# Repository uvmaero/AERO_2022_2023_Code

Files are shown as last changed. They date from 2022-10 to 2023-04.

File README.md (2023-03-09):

# AERO_2022-2023
All of the code that drives each board and runs the car for the year 2022-2023!

## Overview
Each board is managed by an ESP32-WROOM, in the form of the official Dev-Kit-C V4 from Espressif. Its operations are managed by FreeRTOS and is clocked at 240Mhz.

## Boards
### Front Board
#### Description
Located in the front of the car, this board manages all driver input, the remote data aquisition system, and wireless communications with the steering wheel.
#### I/O
##### Inputs
- Accelorator pedal
- Brake pedal 
- Ready to drive button
- front wheel hall effect sensors
- front wheel ride height potentiometers
- CAN bus
##### Outputs
- CAN bus
- LoRa Radio
- ESP NOW data to wheel board
- Ready to drive LED
- Ready to drive buzzer 
#### Libraries
- LoRa

### Rear Board
#### Description
#### I/O
#### Libraries

### Wheel Board
#### Description
#### I/O
#### Libraries

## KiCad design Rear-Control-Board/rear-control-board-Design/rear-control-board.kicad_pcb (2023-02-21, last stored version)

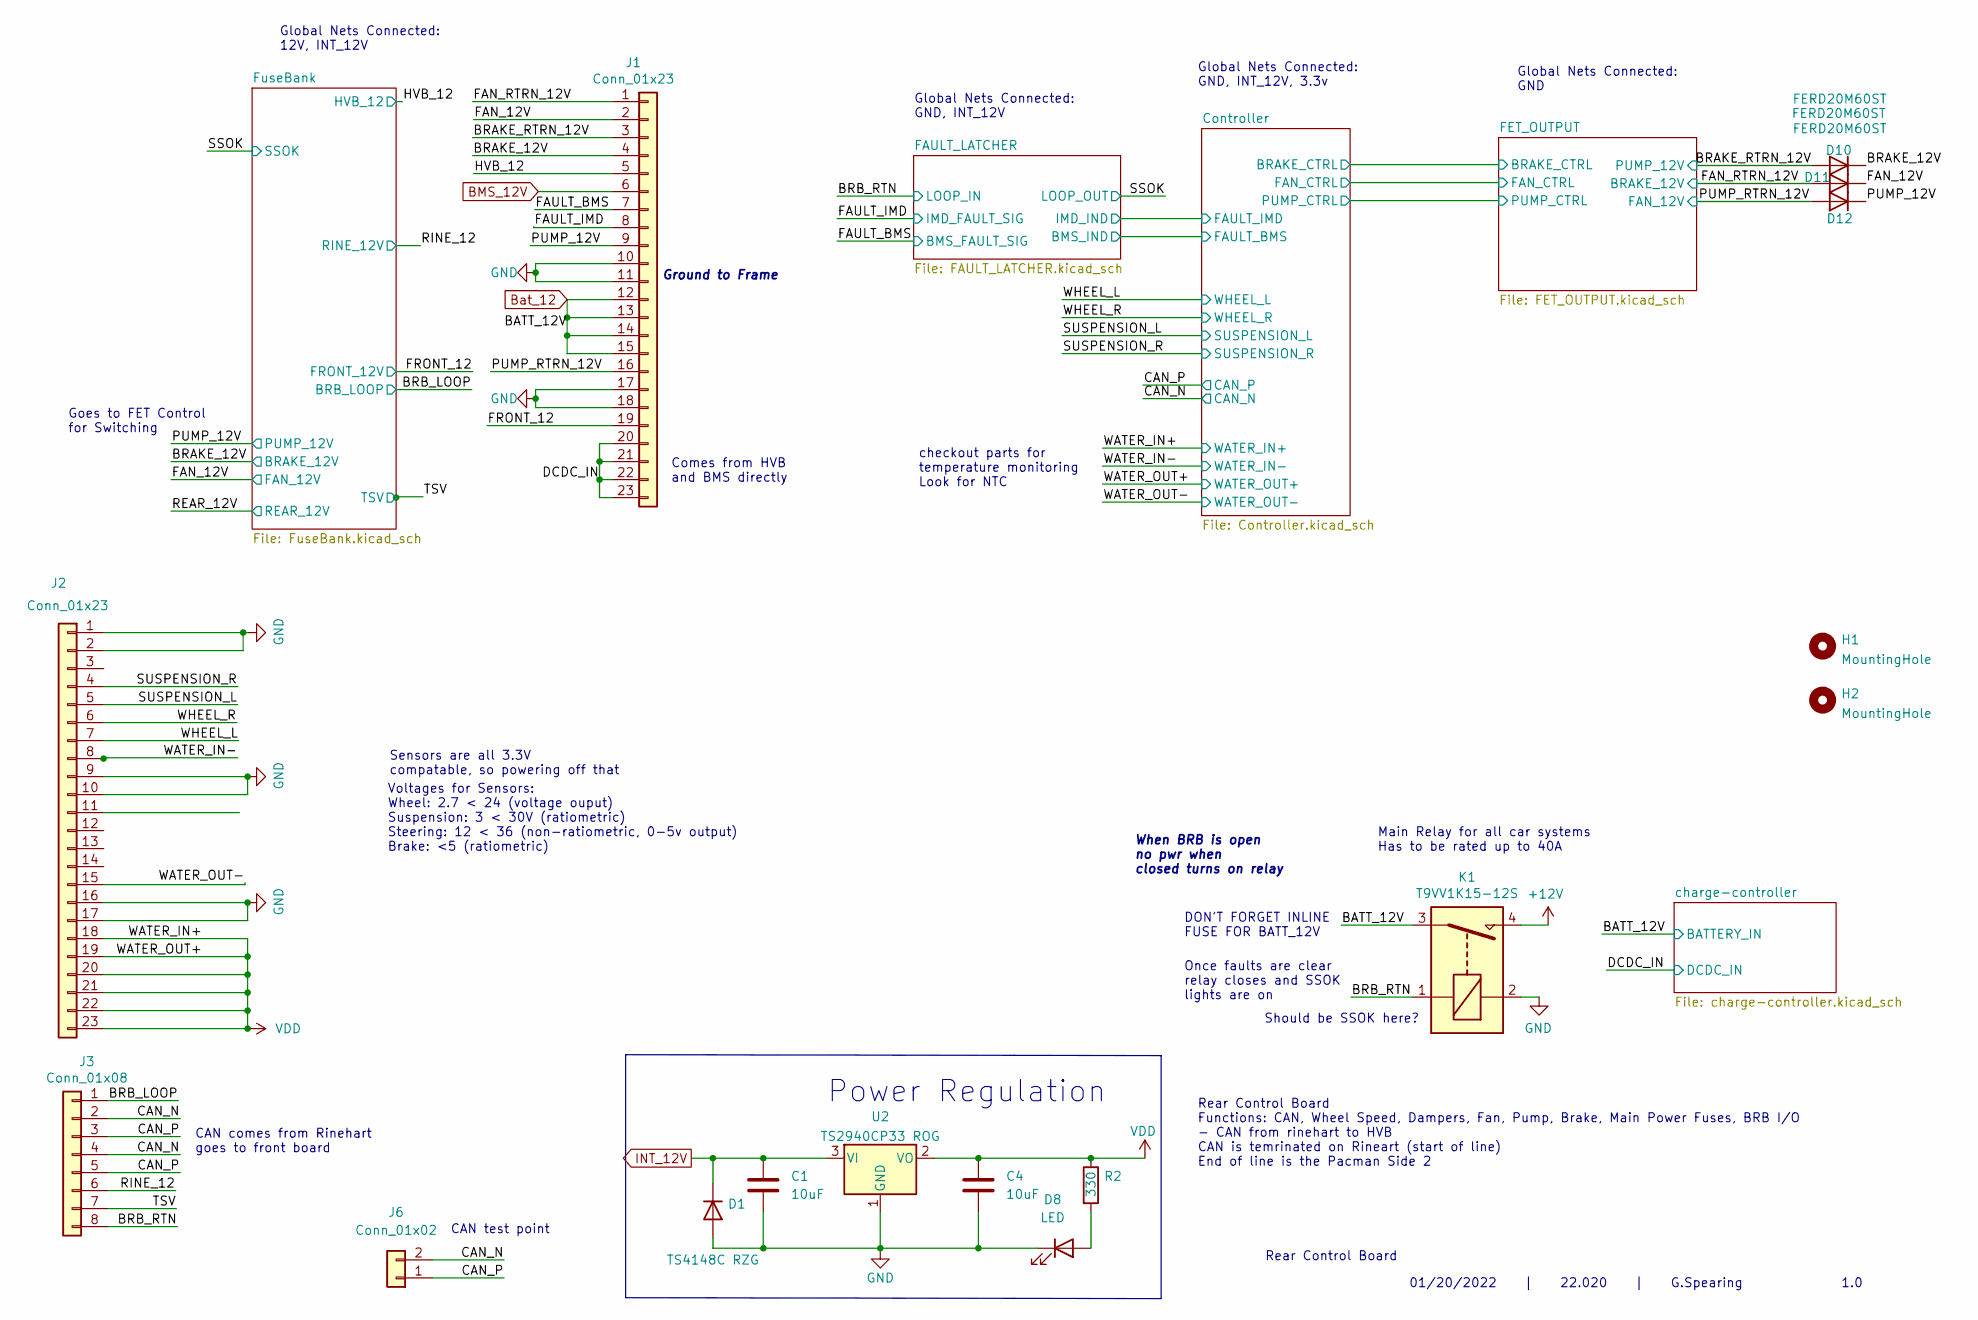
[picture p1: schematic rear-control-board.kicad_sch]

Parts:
C1, C4: 10uF; C_0603_1608Metric_Pad1.08x0.95mm_HandSolder
D1: TS4148C RZG; D_0603_1608Metric_Pad1.05x0.95mm_HandSolder
D8: LED; LED_0603_1608Metric_Pad1.05x0.95mm_HandSolder
D10, D11, D12: FERD20M60ST; TO-220-3_Vertical
H1, H2: MountingHole; MountingHole_3.2mm_M3
J1, J2: Conn_01x23; TE_1-770669-1_23pin_Horizontal
J3: Conn_01x08; TE_1-776280-1_8pin_Horizontal
J6: Conn_01x02; JST_NV_B02P-NV_1x02_P5.00mm_Vertical
K1: T9VV1K15-12S; RELAY_T9VV1K15-12S
R2: 330; R_0603_1608Metric_Pad0.98x0.95mm_HandSolder
U2: TS2940CP33 ROG; TO-252-2

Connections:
/BATT_12V: J1.12, J1.13, J1.14, J1.15, K1.3; also elsewhere on the board
/BRAKE_12V: D10.2 (K), J1.4; also elsewhere on the board
/BRAKE_RTRN_12V: D10.1 (A), J1.3; also elsewhere on the board
/BRB_LOOP: J3.1; also elsewhere on the board
/BRB_RTN: J3.8, K1.1; also elsewhere on the board
/CAN_N: J3.2, J3.4, J6.2; also elsewhere on the board
/CAN_P: J3.3, J3.5, J6.1; also elsewhere on the board
/DCDC_IN: J1.20, J1.21, J1.22, J1.23; also elsewhere on the board
/FAN_12V: D11.2 (K), J1.2; also elsewhere on the board
/FAN_RTRN_12V: D11.1 (A), J1.1; also elsewhere on the board
/FAULT_BMS: J1.7; also elsewhere on the board
/FAULT_IMD: J1.8; also elsewhere on the board
/FRONT_12: J1.19; also elsewhere on the board
/HVB_12: J1.5; also elsewhere on the board
/PUMP_12V: D12.2 (K), J1.9; also elsewhere on the board
/PUMP_RTRN_12V: D12.1 (A), J1.16; also elsewhere on the board
/RINE_12: J3.6; also elsewhere on the board
/SUSPENSION_L: J2.5; also elsewhere on the board
/SUSPENSION_R: J2.4; also elsewhere on the board
/TSV: J3.7; also elsewhere on the board
/WATER_IN-: J2.8; also elsewhere on the board
/WATER_OUT-: J2.15; also elsewhere on the board
/WHEEL_L: J2.7; also elsewhere on the board
/WHEEL_R: J2.6; also elsewhere on the board
BMS_12V: J1.6; also elsewhere on the board
GND: C1.2, C4.2, D1.2 (A), D8.1 (K), J1.10, J1.11, J1.17, J1.18, J2.1, J2.2, J2.9, J2.10, J2.16, J2.17, K1.2, U2.1 (GND); also elsewhere on the board
INT_12V: C1.1, D1.1 (K), U2.3 (VI); also elsewhere on the board
unnamed: D8.2 (A), R2.2
VDD: C4.1, J2.18, J2.19, J2.20, J2.21, J2.22, J2.23, R2.1, U2.2 (VO); also elsewhere on the board

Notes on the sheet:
Once faults are clear relay closes and SSOK lights are on
1.0
Comes from HVB and BMS directly
Should be SSOK here?
Global Nets Connected: GND
Main Relay for all car systems Has to be rated up to 40A
checkout parts for temperature monitoring Look for NTC
When BRB is open no pwr when closed turns on relay
Global Nets Connected: GND, INT_12V
Voltages for Sensors: Wheel: 2.7 < 24 (voltage ouput) Suspension: 3 < 30V (ratiometric) Steering: 12 < 36 (non-ratiometric, 0-5v output) Brake: <5 (ratiometric)
DON'T FORGET INLINE FUSE FOR BATT_12V
CAN test point
01/20/2022 | 22.020 | G.Spearing
Rear Control Board Functions: CAN, Wheel Speed, Dampers, Fan, Pump, Brake, Main Power Fuses, BRB I/O - CAN from rinehart to HVB CAN is temrinated on Rineart (start of line) End of line is the Pacman Side 2
Goes to FET Control for Switching
Ground to Frame
CAN comes from Rinehart goes to front board
Power Regulation
Global Nets Connected: GND, INT_12V, 3.3v
Sensors are all 3.3V compatable, so powering off that
Global Nets Connected: 12V, INT_12V
Rear Control Board

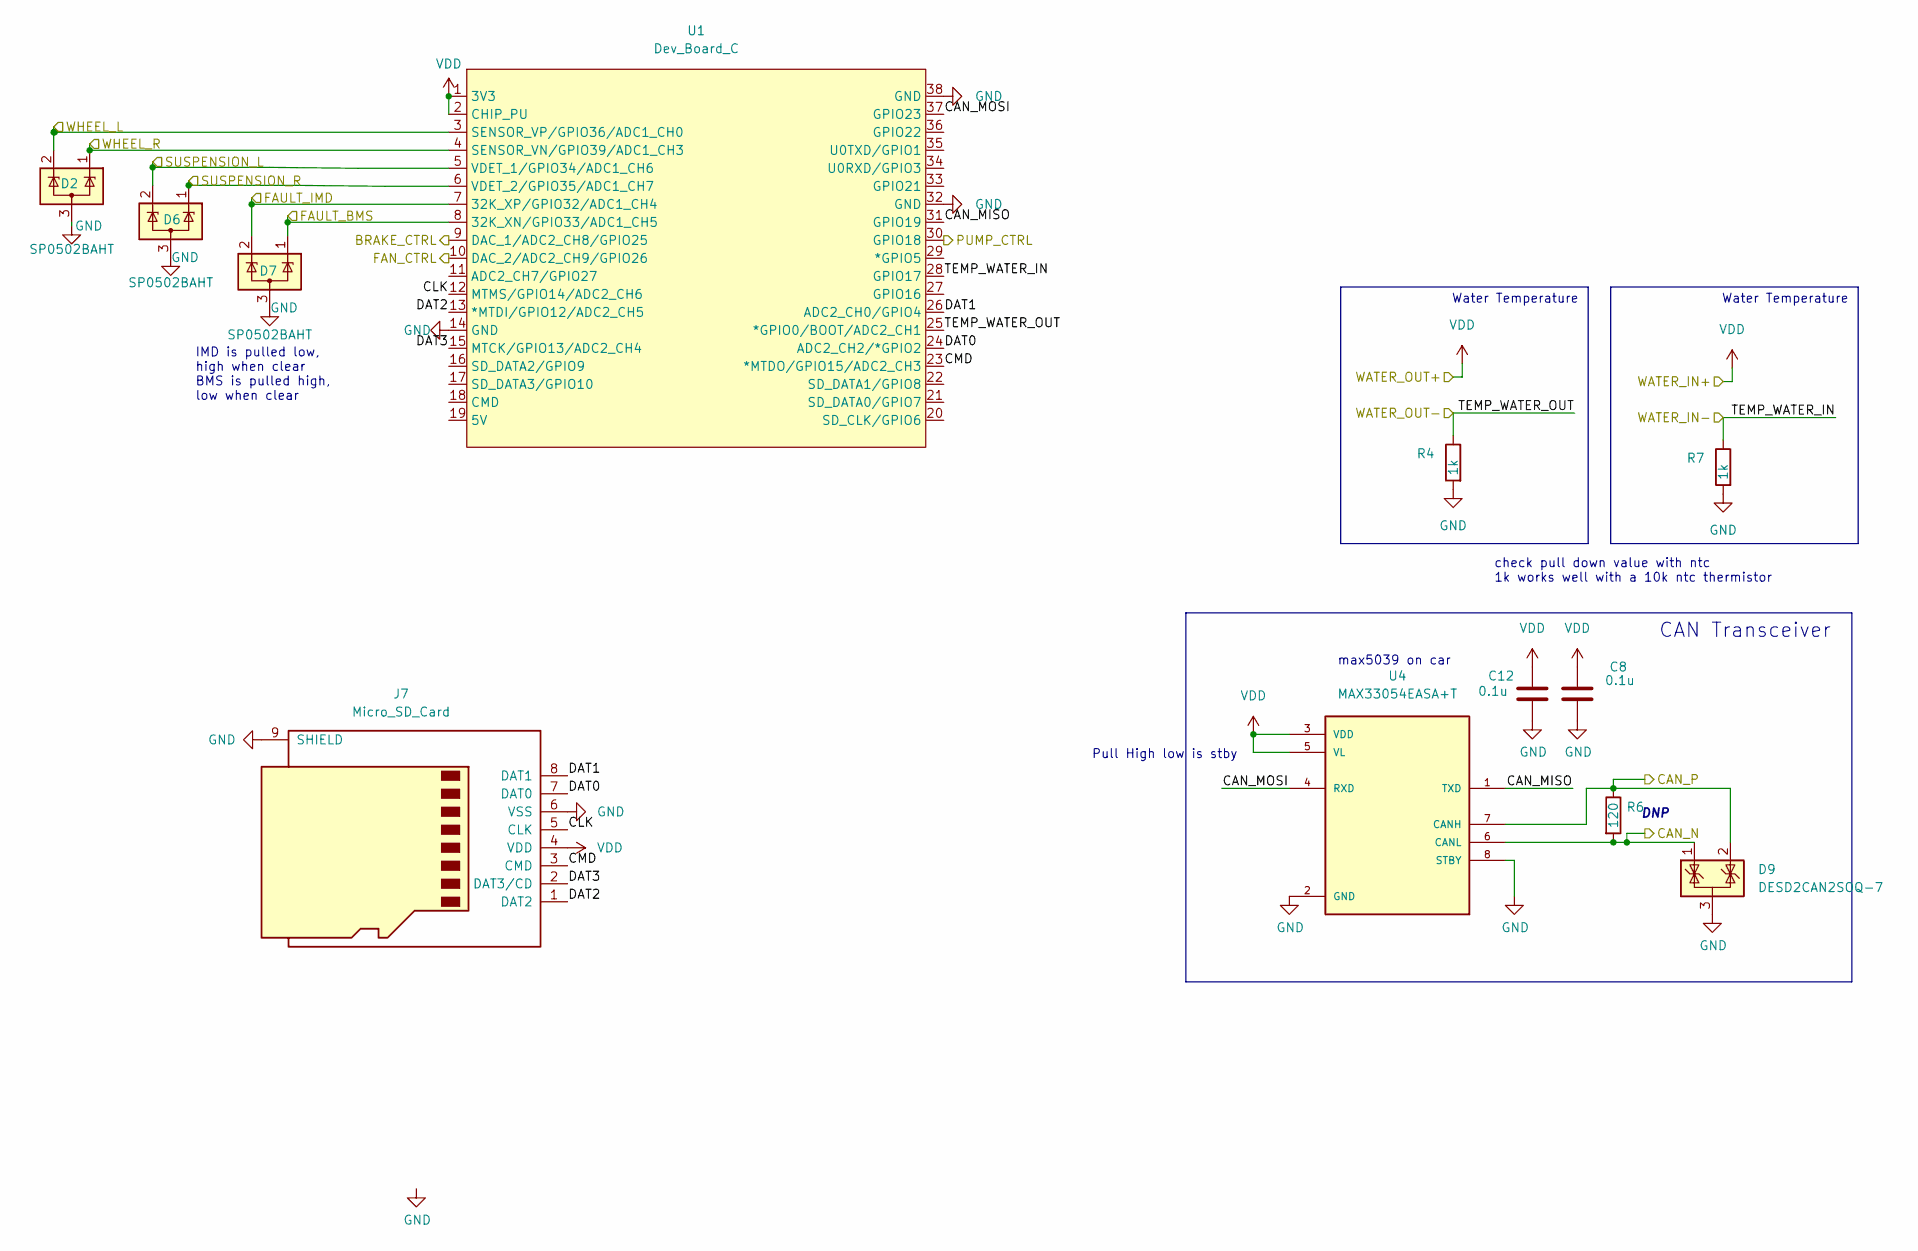
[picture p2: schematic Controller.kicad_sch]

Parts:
C8, C12: 0.1u; C_0603_1608Metric_Pad1.08x0.95mm_HandSolder
D2, D6, D7: SP0502BAHT; SOT-23
D9: DESD2CAN2SOQ-7; SOT-23
J7: Micro_SD_Card; microSD_HC_Wuerth_693072010801
R4, R7: 1k; R_0603_1608Metric_Pad0.98x0.95mm_HandSolder
R6: 120; R_0603_1608Metric_Pad0.98x0.95mm_HandSolder
U1: Dev_Board_C; ESP32-DevKitC
U4: MAX33054EASA+T; SOIC127P600X175-8N

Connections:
/CAN_N: D9.1 (K), R6.2, U4.6 (CANL); also elsewhere on the board
/CAN_P: D9.2 (K), R6.1, U4.7 (CANH); also elsewhere on the board
/Controller/BRAKE_CTRL: U1.9 (DAC_1/ADC2_CH8/GPIO25); also elsewhere on the board
/Controller/CAN_MISO: U1.31 (GPIO19), U4.1 (TXD)
/Controller/CAN_MOSI: U1.37 (GPIO23), U4.4 (RXD)
/Controller/CLK: J7.5 (CLK), U1.12 (MTMS/GPIO14/ADC2_CH6)
/Controller/CMD: J7.3 (CMD), U1.23 (*MTDO/GPIO15/ADC2_CH3)
/Controller/DAT0: J7.7 (DAT0), U1.24 (ADC2_CH2/*GPIO2)
/Controller/DAT1: J7.8 (DAT1), U1.26 (ADC2_CH0/GPIO4)
/Controller/DAT2: J7.1 (DAT2), U1.13 (*MTDI/GPIO12/ADC2_CH5)
/Controller/DAT3: J7.2 (DAT3/CD), U1.15 (MTCK/GPIO13/ADC2_CH4)
/Controller/FAN_CTRL: U1.10 (DAC_2/ADC2_CH9/GPIO26); also elsewhere on the board
/Controller/FAULT_IMD: D7.2 (K), U1.7 (32K_XP/GPIO32/ADC1_CH4); also elsewhere on the board
/Controller/PUMP_CTRL: U1.30 (GPIO18); also elsewhere on the board
/FAULT_LATCHER/BMS_SWITCH: D7.1 (K), U1.8 (32K_XN/GPIO33/ADC1_CH5); also elsewhere on the board
/SUSPENSION_L: D6.2 (K), U1.5 (VDET_1/GPIO34/ADC1_CH6); also elsewhere on the board
/SUSPENSION_R: D6.1 (K), U1.6 (VDET_2/GPIO35/ADC1_CH7); also elsewhere on the board
/WATER_IN-: R7.1, U1.28 (GPIO17); also elsewhere on the board
/WATER_OUT-: R4.1, U1.25 (*GPIO0/BOOT/ADC2_CH1); also elsewhere on the board
/WHEEL_L: D2.2 (K), U1.3 (SENSOR_VP/GPIO36/ADC1_CH0); also elsewhere on the board
/WHEEL_R: D2.1 (K), U1.4 (SENSOR_VN/GPIO39/ADC1_CH3); also elsewhere on the board
GND: C8.2, C12.2, D2.3 (A), D6.3 (A), D7.3 (A), D9.3 (A), J7.6 (VSS), J7.9 (SHIELD), R4.2, R7.2, U1.14 (GND), U1.32 (GND), U1.38 (GND), U4.2 (GND), U4.8 (STBY); also elsewhere on the board
VDD: C8.1, C12.1, J7.4 (VDD), U1.1 (3V3), U1.2 (CHIP_PU), U4.3 (VDD), U4.5 (VL); also elsewhere on the board

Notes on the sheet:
Water Temperature
check pull down value with ntc 1k works well with a 10k ntc thermistor
CAN Transceiver
IMD is pulled low, high when clear BMS is pulled high, low when clear
max5039 on car
Pull High low is stby
DNP

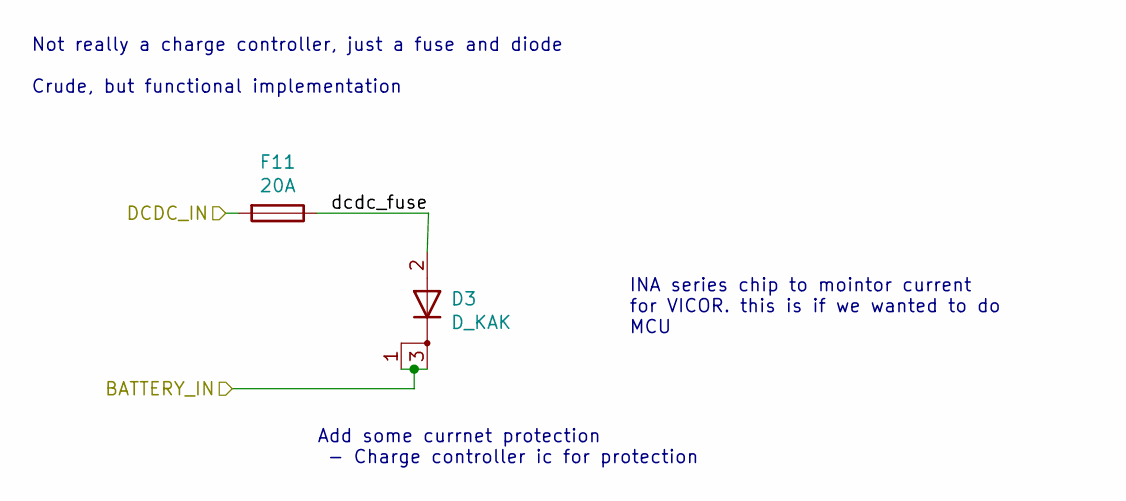
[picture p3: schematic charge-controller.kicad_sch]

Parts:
D3: D_KAK; TO-252-2
F11: 20A; Fuseholder_Blade_Mini_Keystone_3568

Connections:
/BATT_12V: D3.1 (K), D3.3 (K); also elsewhere on the board
/DCDC_IN: F11.2; also elsewhere on the board
/charge-controller/dcdc_fuse: D3.2 (A), F11.1

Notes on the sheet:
Add some currnet protection - Charge controller ic for protection
Not really a charge controller, just a fuse and diode Crude, but functional implementation
INA series chip to mointor current for VICOR. this is if we wanted to do MCU

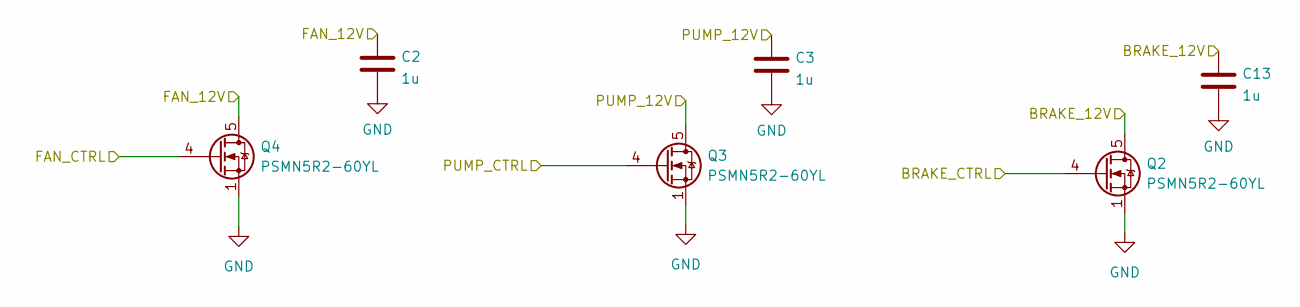
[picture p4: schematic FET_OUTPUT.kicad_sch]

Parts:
C2, C3, C13: 1u; C_0603_1608Metric_Pad1.08x0.95mm_HandSolder
Q2, Q3, Q4: PSMN5R2-60YL; LFPAK56

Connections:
/BRAKE_RTRN_12V: C3.1, Q3.5 (D); also elsewhere on the board
/Controller/BRAKE_CTRL: Q2.4 (G); also elsewhere on the board
/Controller/FAN_CTRL: Q4.4 (G); also elsewhere on the board
/Controller/PUMP_CTRL: Q3.4 (G); also elsewhere on the board
/FAN_RTRN_12V: C13.1, Q2.5 (D); also elsewhere on the board
/PUMP_RTRN_12V: C2.1, Q4.5 (D); also elsewhere on the board
GND: C2.2, C3.2, C13.2, Q2.1 (S), Q2.2 (S), Q2.3 (S), Q3.1 (S), Q3.2 (S), Q3.3 (S), Q4.1 (S), Q4.2 (S), Q4.3 (S); also elsewhere on the board

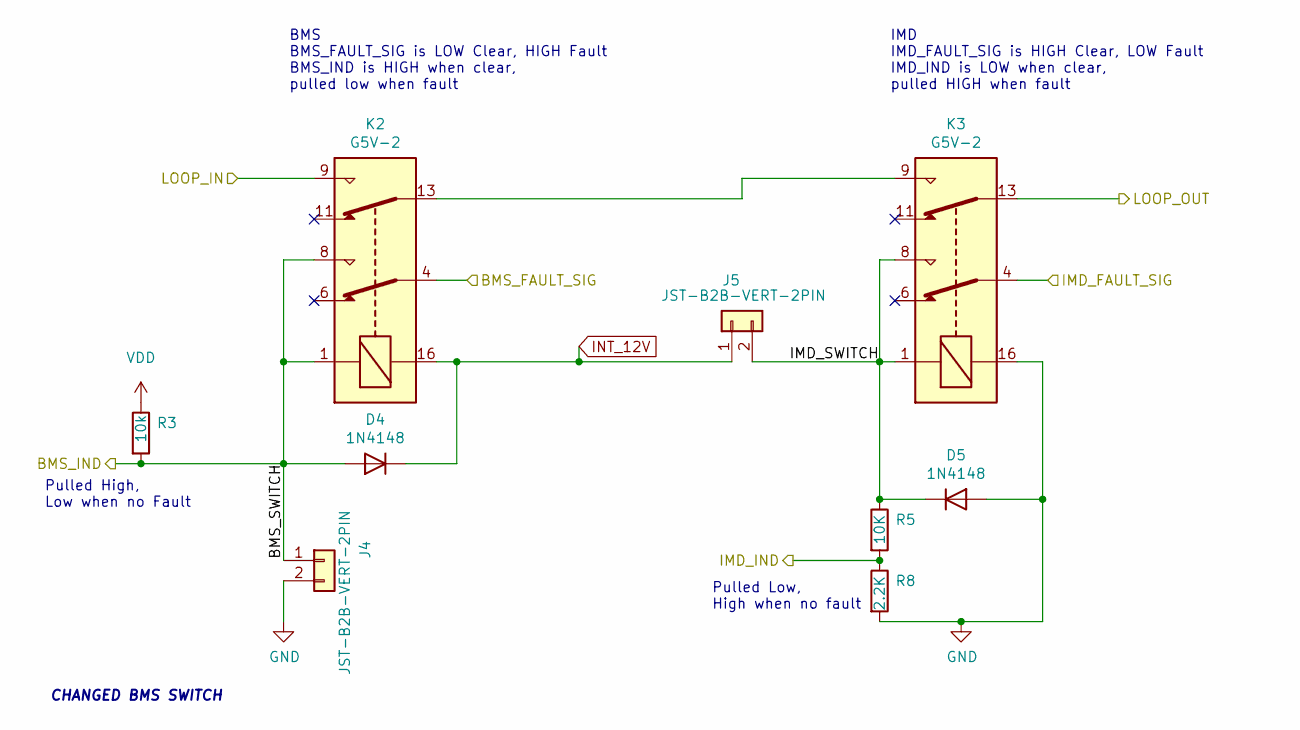
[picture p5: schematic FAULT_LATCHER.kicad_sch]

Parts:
D4, D5: 1N4148; D_SOD-123
J4, J5: JST-B2B-VERT-2PIN; JST_XH_B2B-XH-AM_1x02_P2.50mm_Vertical
K2, K3: G5V-2; Relay_DPDT_Omron_G5V-2
R3: 10k; R_0603_1608Metric_Pad0.98x0.95mm_HandSolder
R5: 10K; R_0603_1608Metric_Pad0.98x0.95mm_HandSolder
R8: 2.2K; R_0603_1608Metric_Pad0.98x0.95mm_HandSolder

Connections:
/BRB_RTN: K2.9; also elsewhere on the board
/Controller/FAULT_IMD: R5.2, R8.1; also elsewhere on the board
/FAULT_BMS: K2.4; also elsewhere on the board
/FAULT_IMD: K3.4; also elsewhere on the board
/FAULT_LATCHER/BMS_SWITCH: D4.2 (A), J4.1, K2.1, K2.8, R3.2; also elsewhere on the board
/FAULT_LATCHER/IMD_SWITCH: D5.1 (K), J5.2, K3.1, K3.8, R5.1
/SSOK: K3.13; also elsewhere on the board
GND: D5.2 (A), J4.2, K3.16, R8.2; also elsewhere on the board
INT_12V: D4.1 (K), J5.1, K2.16; also elsewhere on the board
unnamed: K2.13, K3.9
VDD: R3.1; also elsewhere on the board

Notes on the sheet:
Pulled High, Low when no Fault
IMD IMD_FAULT_SIG is HIGH Clear, LOW Fault IMD_IND is LOW when clear, pulled HIGH when fault
Pulled Low, High when no fault
BMS BMS_FAULT_SIG is LOW Clear, HIGH Fault BMS_IND is HIGH when clear, pulled low when fault
CHANGED BMS SWITCH

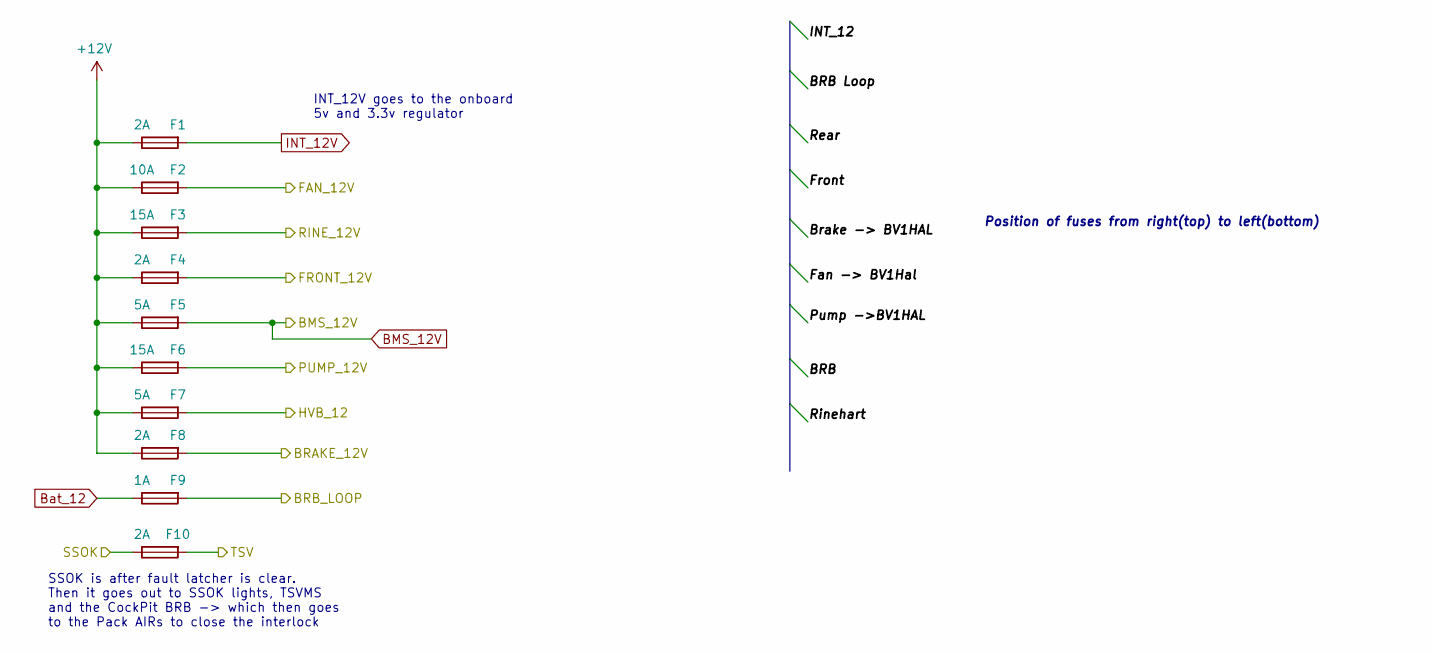
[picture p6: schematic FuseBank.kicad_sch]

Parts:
F1, F4, F8, F10: 2A; Fuseholder_Blade_Mini_Keystone_3568
F2: 10A; Fuseholder_Blade_Mini_Keystone_3568
F3, F6: 15A; Fuseholder_Blade_Mini_Keystone_3568
F5, F7: 5A; Fuseholder_Blade_Mini_Keystone_3568
F9: 1A; Fuseholder_Blade_Mini_Keystone_3568

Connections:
/BRAKE_12V: F8.2; also elsewhere on the board
/BRB_LOOP: F9.2; also elsewhere on the board
/FAN_12V: F2.2; also elsewhere on the board
/FRONT_12: F4.2; also elsewhere on the board
/HVB_12: F7.2; also elsewhere on the board
/PUMP_12V: F6.2; also elsewhere on the board
/RINE_12: F3.2; also elsewhere on the board
/SSOK: F10.1; also elsewhere on the board
/TSV: F10.2; also elsewhere on the board
BMS_12V: F5.2; also elsewhere on the board
INT_12V: F1.2; also elsewhere on the board

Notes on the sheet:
SSOK is after fault latcher is clear. Then it goes out to SSOK lights, TSVMS and the CockPit BRB -> which then goes to the Pack AIRs to close the interlock
Position of fuses from right(top) to left(bottom)
INT_12V goes to the onboard 5v and 3.3v regulator

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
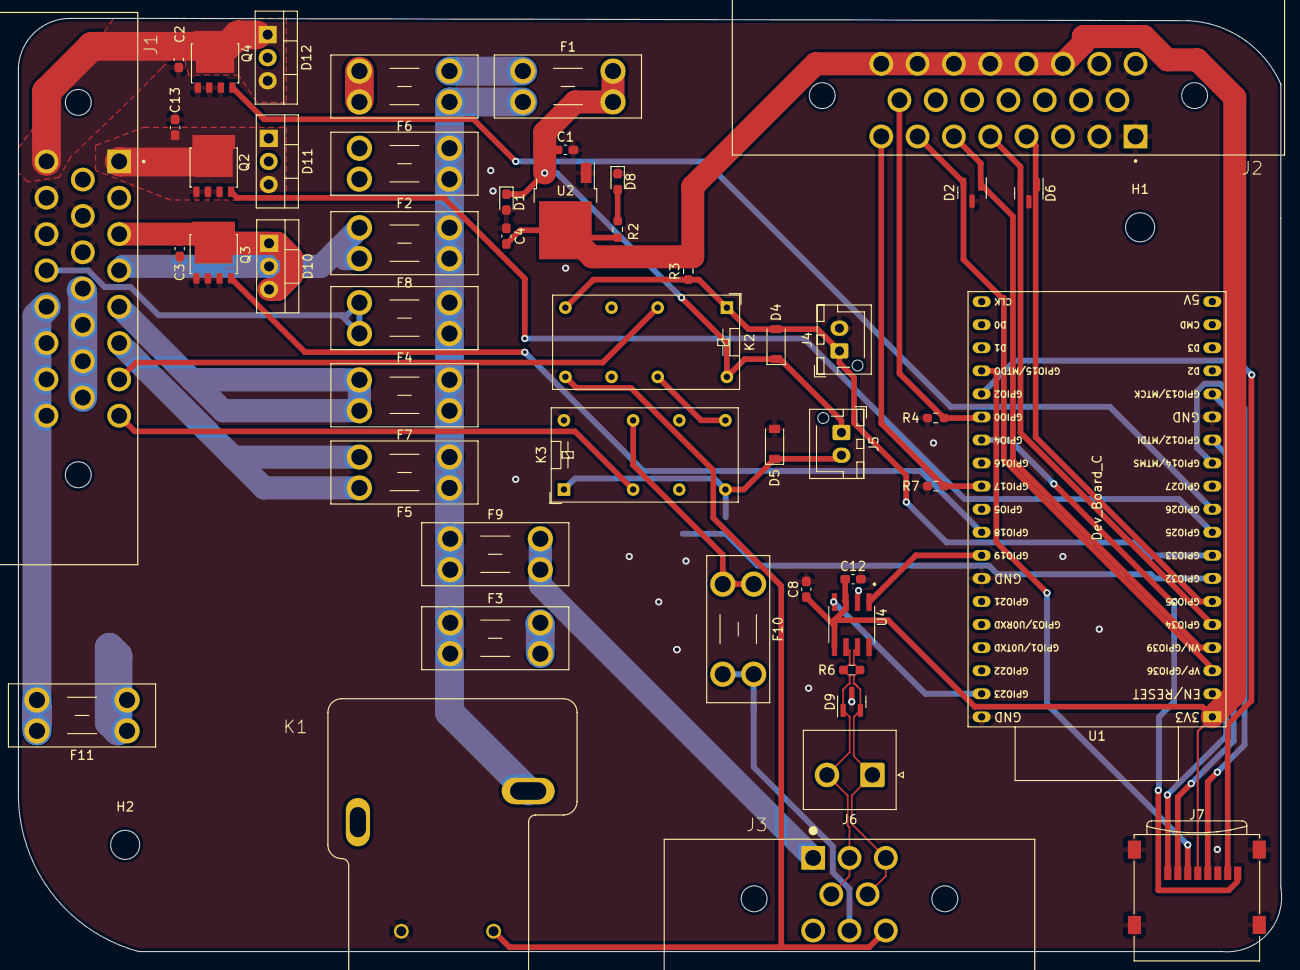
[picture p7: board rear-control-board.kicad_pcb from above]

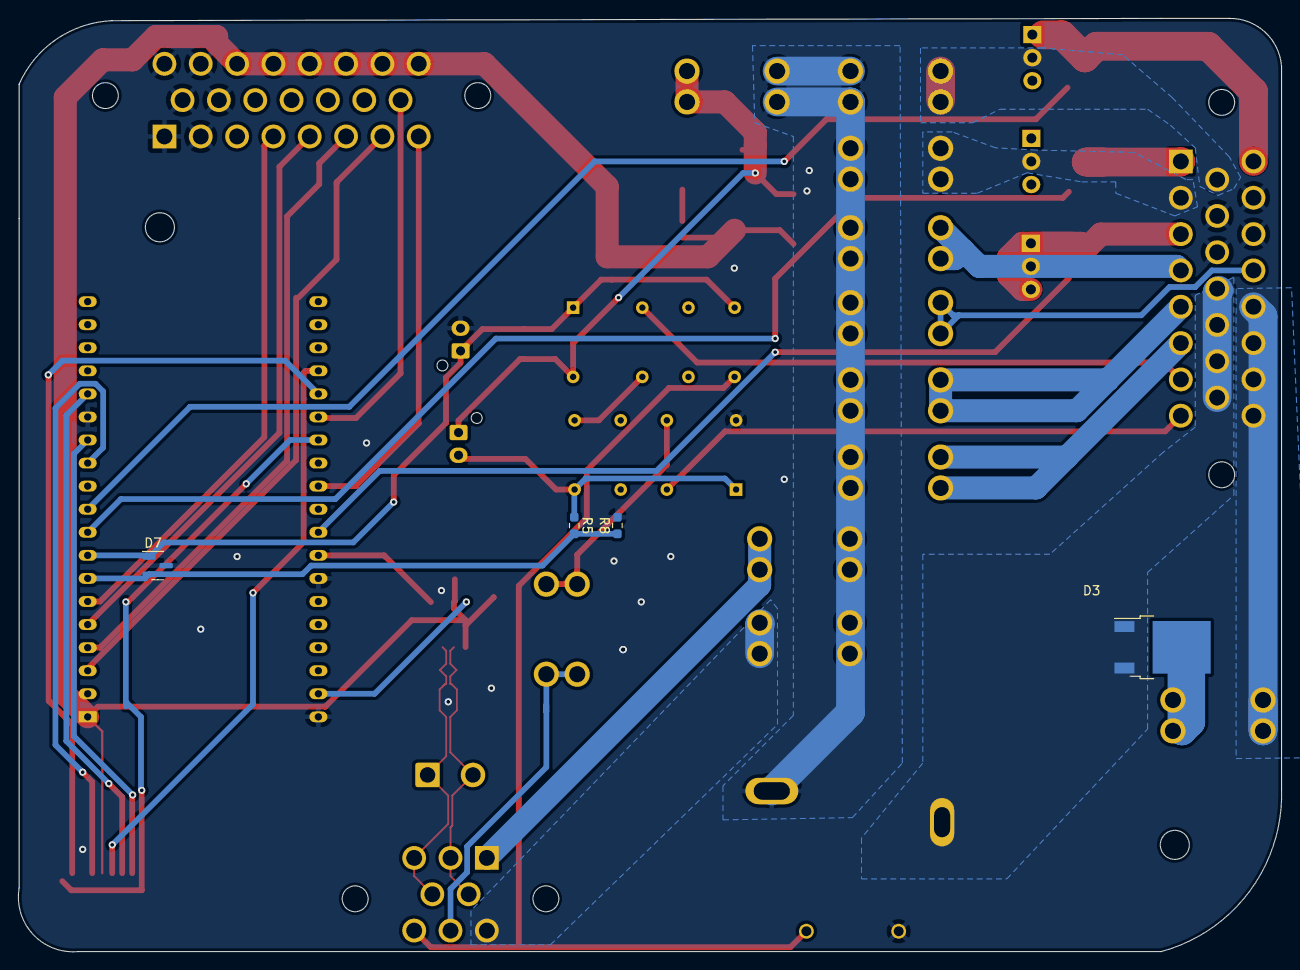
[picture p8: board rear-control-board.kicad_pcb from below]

Board: 2 copper layers, 139.1 x 102.8 mm, 55 parts (4 on the bottom side), 47 nets.

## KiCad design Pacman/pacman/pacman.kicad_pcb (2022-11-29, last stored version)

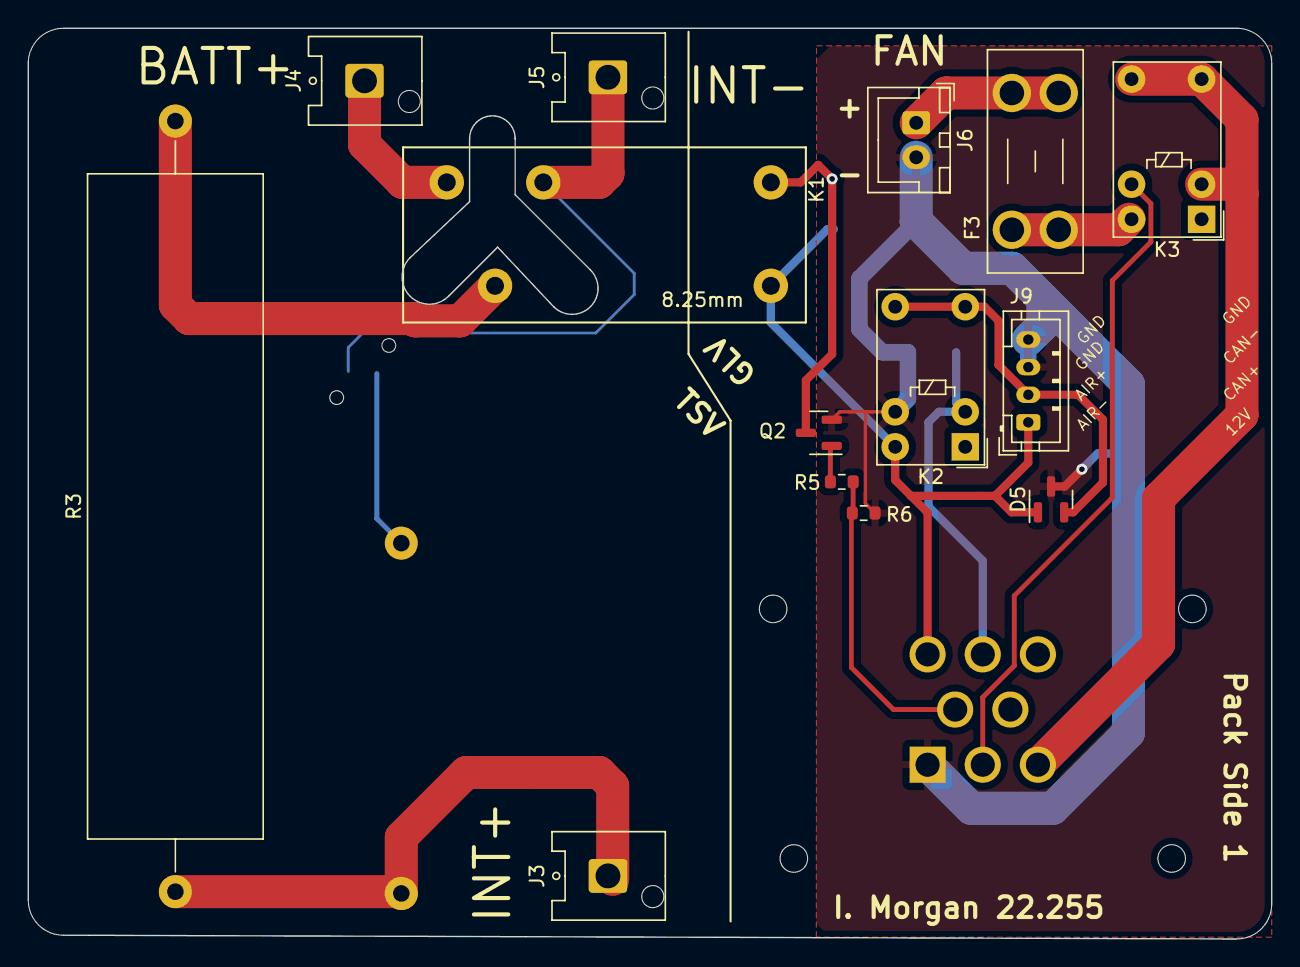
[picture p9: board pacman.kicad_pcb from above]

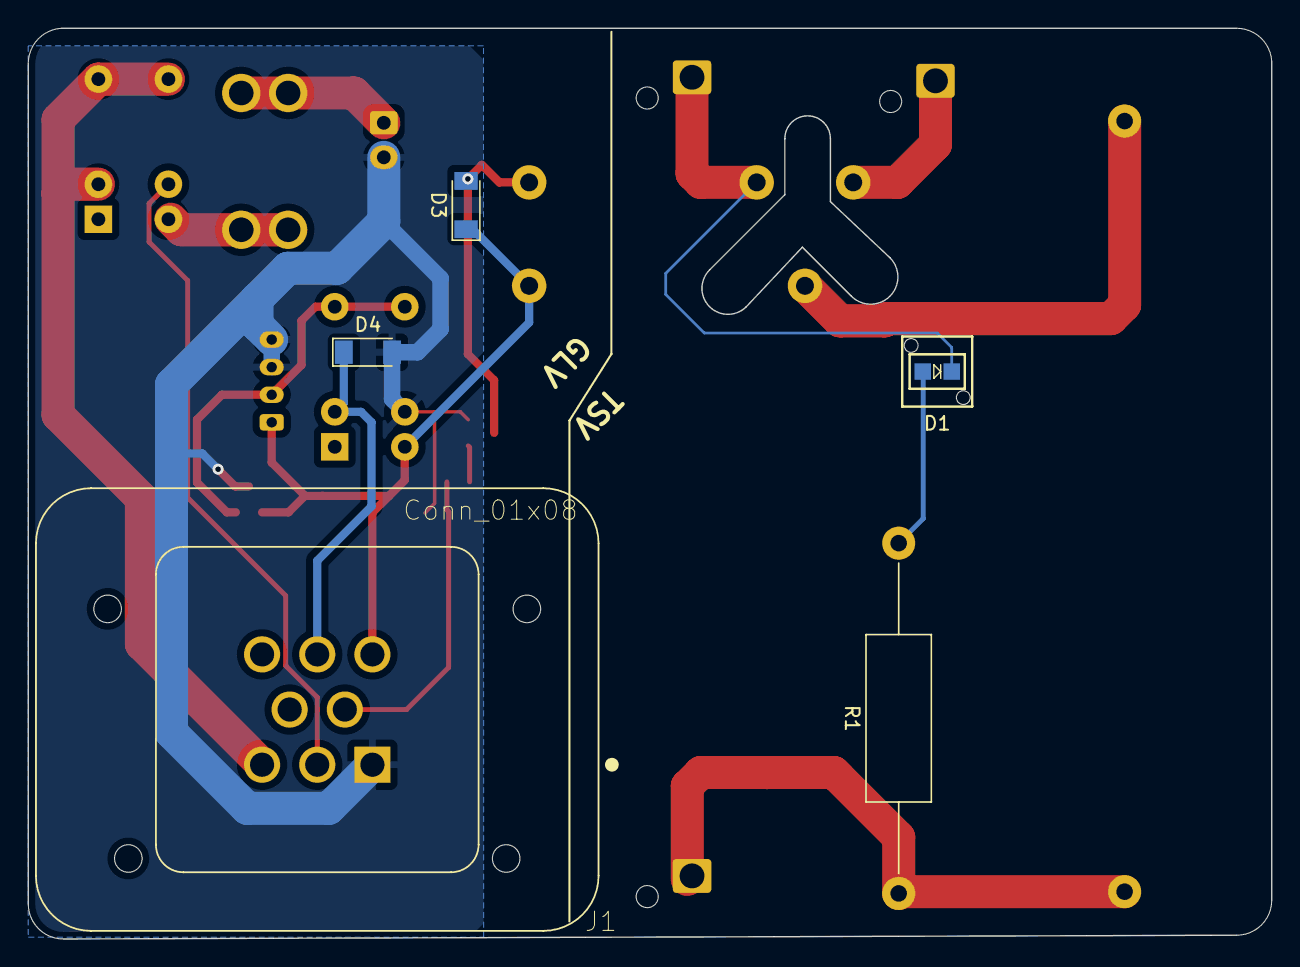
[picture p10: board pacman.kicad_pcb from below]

Board: 2 copper layers, 90.2 x 66.0 mm, 19 parts (5 on the bottom side), 16 nets.

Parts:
D1: LED; LPA-C011301S-x LED 0805 LIGHT PIPE SINGLE VERT SMD
D3, D4: 1N4148; D_MiniMELF
D5: MMBZxx; SOT-23
F3: Fuse; Fuseholder_Blade_Mini_Keystone_3568
J1: Conn_01x08; TE_1-776276-1_8pin_Vertical
J3, J4, J5: Conn_01x01; Hirose_DF63M-1P-3.96DSA_1x01_P3.96mm_Vertical
J6: Conn_01x02; JST_XH_B2B-XH-A_1x02_P2.50mm_Vertical
J9: JST PH; JST_PH_B4B-PH-K_1x04_P2.00mm_Vertical
K1: G2RL
K2, K3: G5V-1; Relay_SPDT_Omron_G5V-1
Q2: MMBT2222A; SOT-23
R1: 1.5k; R_Axial_DIN0414_L11.9mm_D4.5mm_P25.40mm_Horizontal
R3: 500; R_Axial_Power_L48.0mm_W12.5mm_P55.88mm
R5: 10k; R_0603_1608Metric
R6: 2k; R_0603_1608Metric

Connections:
+12V: J1.3, K3.2, K3.5, K3.6
/AIR_B+: D5.2 (K), J9.2, K2.5, K2.6
/AIR_B-: D3.1 (K), D5.1 (K), J1.6, J9.1, K1.2, K2.10
/B+: J4.1, K1.10
/BMS_FAN: J1.2, K3.9
/FAN_OUT: F3.1, K3.10
/INT+: J3.1, R1.1, R3.1
/INT-: D1.1 (K), J5.1, K1.1
/MAIN_CONT: D4.1 (K), J1.7, K2.2
/PRECHARGE: J1.4, R5.2, R6.2
GND: D4.2 (A), D5.3 (A), J1.1, J6.2, J9.3, J9.4, K2.9, Q2.2 (E), R6.1
unnamed: D1.2 (A), R1.2
unnamed: D3.2 (A), K1.9, Q2.3 (C)
unnamed: F3.2, J6.1
unnamed: K1.5, R3.2
unnamed: Q2.1 (B), R5.1

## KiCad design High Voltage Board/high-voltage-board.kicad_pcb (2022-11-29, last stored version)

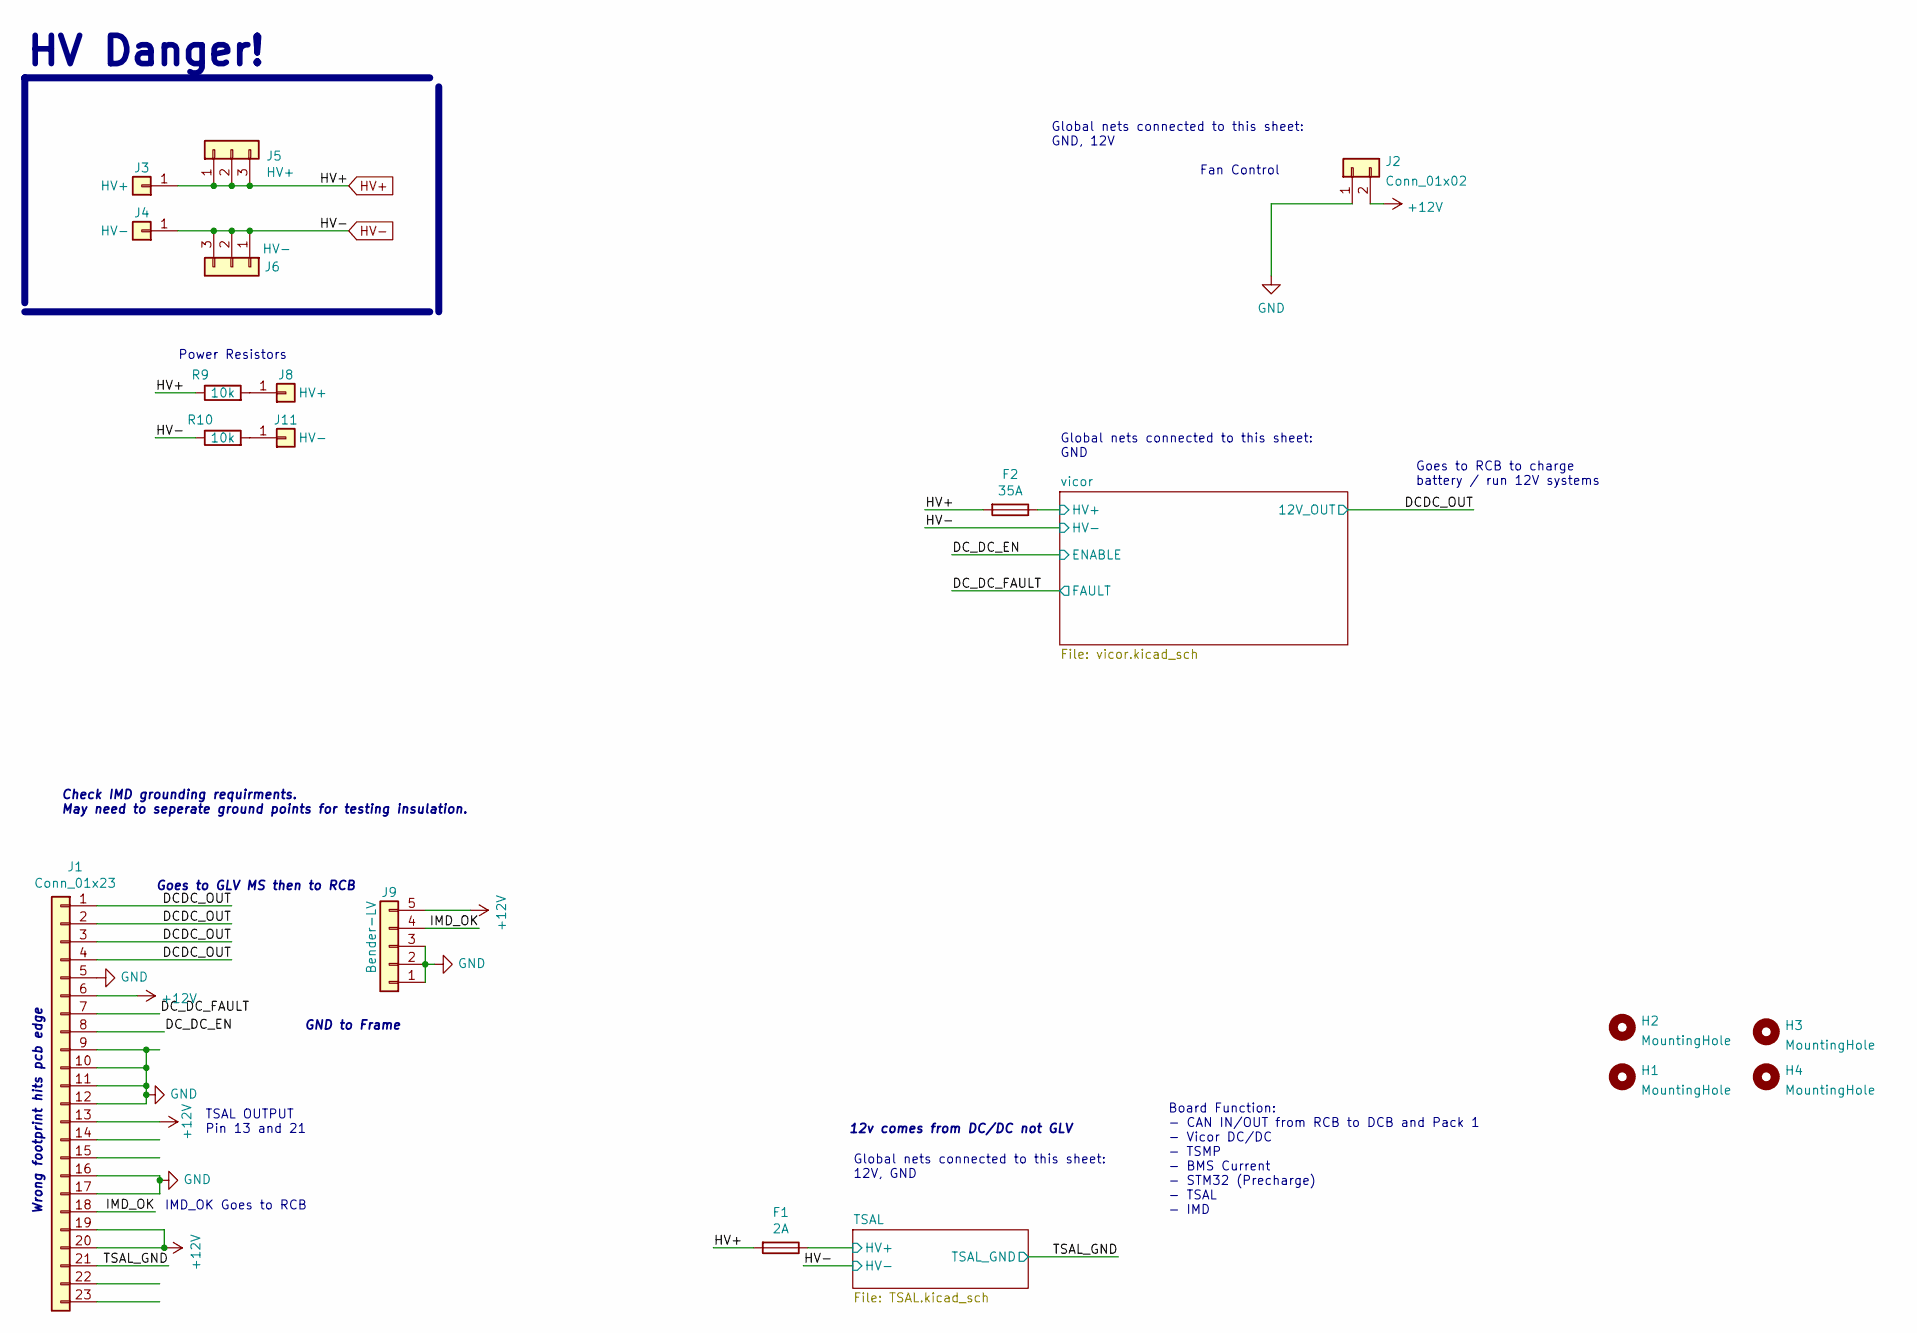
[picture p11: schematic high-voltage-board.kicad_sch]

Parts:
F1: 2A; Fuseholder_Cylinder-5x20mm_Schurter_0031_8201_Horizontal_Op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
F2: 35A; Fuseholder_Cylinder-5x20mm_Schurter_0031_8201_Horizontal_Op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
H1, H2, H3, H4: MountingHole; MountingHole_3.2mm_M3
J1: Conn_01x23; TE_1-770669-1_23pin_Horizontal
J2: Conn_01x02; JST_XH_B2B-XH-A_1x02_P2.50mm_Vertical
J3, J8: HV+; Hirose_DF63M-1P-3.96DSA_1x01_P3.96mm_Vertical
J4, J11: HV-; Hirose_DF63M-1P-3.96DSA_1x01_P3.96mm_Vertical
J5: HV+; TE_MATE-N-LOK_1-770870-x_1x03_P4.14mm_Vertical
J6: HV-; TE_MATE-N-LOK_1-770870-x_1x03_P4.14mm_Vertical
J9: Bender-LV; JST_XH_B5B-XH-A_1x05_P2.50mm_Vertical
R9, R10: 10k; R_Axial_Power_L50.0mm_W9.0mm_P60.96mm

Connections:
+12V: J1.6, J1.13, J1.19, J1.20, J2.2, J9.5; also elsewhere on the board
/DCDC_OUT: J1.1, J1.2, J1.3, J1.4; also elsewhere on the board
/DC_DC_EN: J1.8; also elsewhere on the board
/DC_DC_FAULT: J1.7; also elsewhere on the board
/IMD_OK: J1.18, J9.4
/TSAL/HV+: F1.1; also elsewhere on the board
/TSAL_GND: J1.21; also elsewhere on the board
/vicor/HV+: F2.1; also elsewhere on the board
GND: J1.5, J1.9, J1.10, J1.11, J1.12, J1.16, J1.17, J2.1, J9.1, J9.2, J9.3; also elsewhere on the board
HV+: F1.2, F2.2, J3.1, J5.1, J5.2, J5.3, R9.1
HV-: J4.1, J6.1, J6.2, J6.3, R10.1; also elsewhere on the board
unnamed: J8.1, R9.2
unnamed: J11.1, R10.2

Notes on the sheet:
Global nets connected to this sheet: GND, 12V
Global nets connected to this sheet: 12V, GND
IMD_OK Goes to RCB
Goes to RCB to charge battery / run 12V systems
TSAL OUTPUT Pin 13 and 21
Board Function: - CAN IN/OUT from RCB to DCB and Pack 1 - Vicor DC/DC - TSMP - BMS Current - STM32 (Precharge) - TSAL - IMD
Power Resistors
12v comes from DC/DC not GLV
Goes to GLV MS then to RCB
Fan Control
GND to Frame
Global nets connected to this sheet: GND
HV Danger!
Check IMD grounding requirments. May need to seperate ground points for testing insulation.
Wrong footprint hits pcb edge

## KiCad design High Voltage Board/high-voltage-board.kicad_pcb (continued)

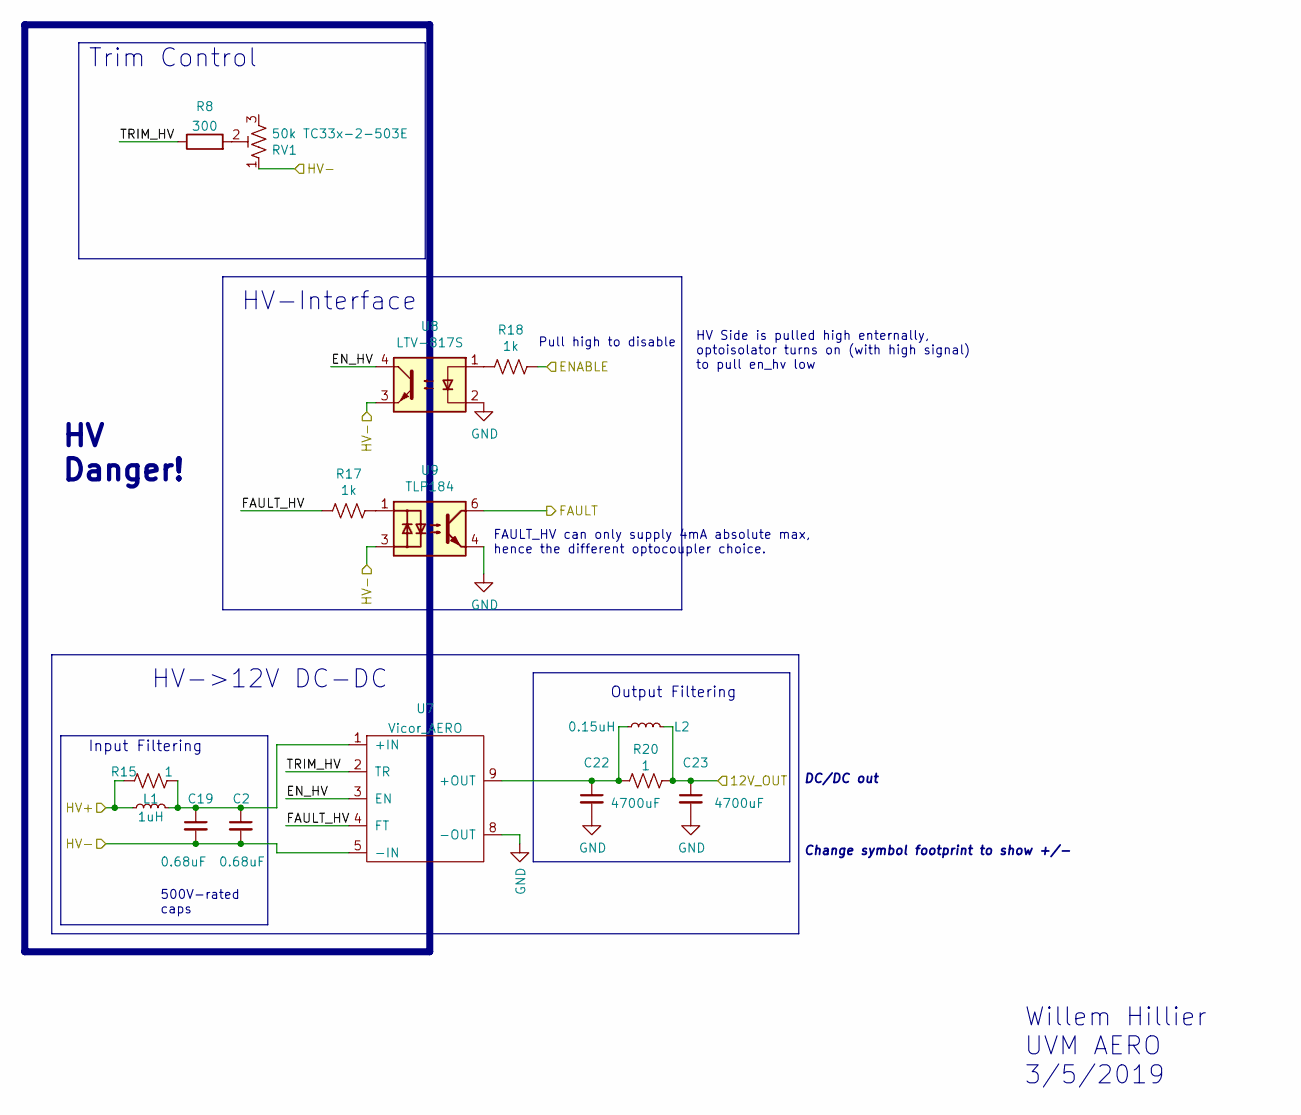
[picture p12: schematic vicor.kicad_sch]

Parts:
C2, C19: 0.68uF; C_Rect_L18.0mm_W8.0mm_P15.00mm_FKS3_FKP3
C22, C23: 4700uF; C_Radial_D18.0mm_H35.5mm_P7.50mm
L1: 1uH; L_1008_2520Metric_Pad1.43x2.20mm_HandSolder
L2: 0.15uH; L_0805_2012Metric_Pad1.15x1.40mm_HandSolder
R8: 300; R_0603_1608Metric_Pad0.98x0.95mm_HandSolder
R15, R20: 1; R_2512_6332Metric_Pad1.40x3.35mm_HandSolder
R17, R18: 1k; R_0603_1608Metric_Pad0.98x0.95mm_HandSolder
RV1: 50k TC33x-2-503E; Potentiometer_Bourns_TC33X_Vertical
U7: Vicor_AERO; vicor-socket-no-cutouts
U8: LTV-817S; SMDIP-4_W9.53mm_Clearance8mm
U9: TLP184; MFSOP6-4_4.4x3.6mm_P1.27mm

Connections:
/DCDC_OUT: C23.1, L2.2, R20.1; also elsewhere on the board
/DC_DC_EN: R18.1; also elsewhere on the board
/DC_DC_FAULT: U9.6; also elsewhere on the board
/vicor/EN_HV: U7.3 (EN), U8.4
/vicor/FAULT_HV: R17.2, U7.4 (FT)
/vicor/HV+: L1.1, R15.2; also elsewhere on the board
/vicor/TRIM_HV: R8.1, U7.2 (TR)
GND: C22.2, C23.2, U7.8 (-OUT), U8.2, U9.4; also elsewhere on the board
HV-: C2.2, C19.2, RV1.1, U7.5 (-IN), U8.3, U9.3; also elsewhere on the board
unnamed: C2.1, C19.1, L1.2, R15.1, U7.1 (+IN)
unnamed: C22.1, L2.1, R20.2, U7.9 (+OUT)
unnamed: R8.2, RV1.2
unnamed: R17.1, U9.1
unnamed: R18.2, U8.1

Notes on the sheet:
DC/DC out
Output Filtering
500V-rated caps
Willem Hillier UVM AERO 3/5/2019
Input Filtering
Trim Control
HV-Interface
Change symbol footprint to show +/-
Pull high to disable
HV->12V DC-DC
HV Side is pulled high enternally, optoisolator turns on (with high signal) to pull en_hv low
HV Danger!
FAULT_HV can only supply 4mA absolute max, hence the different optocoupler choice.


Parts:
C4, C5: 0.1u; C_0603_1608Metric_Pad1.08x0.95mm_HandSolder
C6: 1u; C_0603_1608Metric_Pad1.08x0.95mm_HandSolder
Q1, Q2: PSMN5R2-60YL; LFPAK56
R1: 39k; R_Axial_DIN0411_L9.9mm_D3.6mm_P25.40mm_Horizontal
R2, R5: 10k; R_0603_1608Metric_Pad0.98x0.95mm_HandSolder
R3: 100k; R_0603_1608Metric_Pad0.98x0.95mm_HandSolder
R4: 235k; R_0603_1608Metric_Pad0.98x0.95mm_HandSolder
R6: 0.75; R_2512_6332Metric_Pad1.40x3.35mm_HandSolder
U2: LTV-817S; SMDIP-4_W9.53mm_Clearance8mm
U3: LM555xM; SOIC-8_3.9x4.9mm_P1.27mm

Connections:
+12V: U2.4; also elsewhere on the board
/TSAL/555_OUT: R5.2, U3.3 (Q)
/TSAL/HV+: R1.2; also elsewhere on the board
/TSAL/pass: C6.1, R4.2, U3.2 (TR), U3.6 (THR)
/TSAL_GND: Q2.5 (D); also elsewhere on the board
GND: C4.2, C5.2, C6.2, Q1.1 (S), Q1.2 (S), Q1.3 (S), R2.2, R6.1, U3.1 (GND); also elsewhere on the board
HV-: U2.2; also elsewhere on the board
unnamed: C4.1, U3.5 (CV)
unnamed: Q1.4 (G), Q2.1 (S), Q2.2 (S), Q2.3 (S), R6.2
unnamed: Q1.5 (D), Q2.4 (G), R5.1
unnamed: R1.1, U2.1
unnamed: R3.2, R4.1, U3.7 (DIS)
VCC: C5.1, R2.1, R3.1, U2.3, U3.4 (R), U3.8 (VCC)

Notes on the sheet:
Check footprint/ device mounting, add actual part number
DC/DC Power
Change R6 for Current Rating
CC Output
LED Connector
High Voltage
not sure why but this doesnt work with a 51k for R3 and a 683k + 237k in series for R4 now its about 3Hz cycle CONFUSED



Board: 2 copper layers, 179.2 x 115.7 mm, 43 parts (10 on the bottom side), 29 nets.

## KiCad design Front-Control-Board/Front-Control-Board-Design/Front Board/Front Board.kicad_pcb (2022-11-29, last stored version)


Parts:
C1, C2: 10uF; C_0603_1608Metric_Pad1.08x0.95mm_HandSolder
C3, C4: 0.1u; C_0603_1608Metric_Pad1.08x0.95mm_HandSolder
D1: DESD2CAN2SOQ-7; SOT-23
D2: LED; LED_0603_1608Metric_Pad1.05x0.95mm_HandSolder
D3: SP0503BAHT; SOT-143
D4, D5, D6: SP0502BAHT; SOT-23
D7: TS4148C RZG; D_0603_1608Metric_Pad1.05x0.95mm_HandSolder
J1, J2: Conn_01x14; TE_1-776266-1_14pin_Horizontal
J3: Conn_01x08; TE_1-776280-1_8pin_Horizontal
Q1: 2N7002; SOT-23
R1: 120; R_0603_1608Metric_Pad0.98x0.95mm_HandSolder
R2: 330; R_0603_1608Metric_Pad0.98x0.95mm_HandSolder
R3, R7, R8: 10k; R_0603_1608Metric_Pad0.98x0.95mm_HandSolder
R4, R5, R6, R9: 100; R_0603_1608Metric_Pad0.98x0.95mm_HandSolder
U1: MAX33054EASA+T; SOIC127P600X175-8N
U2: TS2940CP33 ROG; TO-252-2
U3: ESP32-DevKitC

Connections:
+12V: C1.1, D7.1 (K), J1.10, J3.1, J3.2, U2.3 (VI)
/AMS_Led: J2.5, R4.2
/Brake_0: D6.2 (K), J2.2, U3.26 (ADC2_CH0/GPIO4)
/Brake_1: D6.1 (K), J2.6, U3.25 (*GPIO0/BOOT/ADC2_CH1)
/CAN_CS: U1.8 (STBY), U3.29 (*GPIO5)
/CAN_MISO: U1.4 (RXD), U3.31 (GPIO19)
/CAN_MOSI: U1.1 (TXD), U3.37 (GPIO23)
/CAN_N: D1.2 (K), J2.14, R1.2, U1.6 (CANL)
/CAN_P: D1.1 (K), J2.13, R1.1, U1.7 (CANH)
/CAN_SCK: U3.30 (GPIO18)
/IMD_led: J2.8, R5.1
/LORA Reset: J2.9, R8.2, U3.36 (GPIO22)
/LORA_MISO: J1.5, U3.13 (*MTDI/GPIO12/ADC2_CH5)
/LORA_SCK: J1.9, U3.12 (MTMS/GPIO14/ADC2_CH6)
/L_sus: D3.2 (K), J1.2, U3.5 (VDET_1/GPIO34/ADC1_CH6)
/L_wheel: D3.3 (K), J1.11, U3.4 (SENSOR_VN/GPIO39/ADC1_CH3)
/Laura_MOSI: J1.14, U3.15 (MTCK/GPIO13/ADC2_CH4)
/LoRa_CS: J2.1, U3.23 (*MTDO/GPIO15/ADC2_CH3)
/RTD_bttn: J2.7, R7.1, U3.28 (GPIO17)
/RTD_ind_out: J2.11, Q1.3 (D)
/RTD_ind_sig: Q1.1 (G), R3.1, U3.27 (GPIO16)
/RTD_led: J2.4, R6.2
/R_sus: D4.1 (K), J1.7, U3.6 (VDET_2/GPIO35/ADC1_CH7)
/R_wheel: D3.4 (K), J1.1, U3.3 (SENSOR_VP/GPIO36/ADC1_CH0)
/WCB_status: J1.4, R9.2
/pedal_0: D5.1 (K), J1.12, U3.8 (32K_XN/GPIO33/ADC1_CH5)
/pedal_1: D5.2 (K), J1.8, U3.9 (DAC_1/ADC2_CH8/GPIO25)
/stearing: D4.2 (K), J1.3, U3.7 (32K_XP/GPIO32/ADC1_CH4)
GND: C1.2, C2.2, C3.2, C4.2, D1.3 (A), D2.1 (K), D3.1 (A), D4.3 (A), D5.3 (A), D6.3 (A), D7.2 (A), J1.13, Q1.2 (S), R3.2, R7.2, R8.1, U1.2 (GND), U2.1 (GND), U3.14 (GND), U3.32 (GND), U3.38 (GND)
unnamed: D2.2 (A), R2.2
unnamed: R4.1, U3.35 (U0TXD/GPIO1)
unnamed: R5.2, U3.34 (U0RXD/GPIO3)
unnamed: R6.1, U3.33 (GPIO21)
unnamed: R9.1, U3.10 (DAC_2/ADC2_CH9/GPIO26)
VDD: C2.1, C3.1, C4.1, J1.6, J3.3, J3.4, J3.5, J3.6, J3.7, J3.8, R2.1, U1.3 (VDD), U1.5 (VL), U2.2 (VO), U3.1 (3V3), U3.2 (CHIP_PU)

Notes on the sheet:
CAN Transceiver
FRONT BOARD
C.Grund 22.311
Front board -Sensor input, pedals/wheel speed/suspention/wheel position -Wireless communication, Wheel board/LoRa -RTD back up / Indicator -fault lights
STBY logic low is normal mode logic high is receive only



Board: 2 copper layers, 85.2 x 70.7 mm, 27 parts (10 on the bottom side), 34 nets.

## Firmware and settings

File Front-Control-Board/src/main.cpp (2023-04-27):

/**
 * @file main.cpp
 * @author dominic gasperini
 * @brief front control board 
 * @version 1.0
 * @date 2023-04-03
 * 
 * @copyright Copyright (c) 2023
 * 
 * @ref https://espressif-docs.readthedocs-hosted.com/projects/arduino-esp32/en/latest/libraries.html#apis
 */


/*
===============================================================================================
                                    Includes 
===============================================================================================
*/


#include <Arduino.h>
#include <esp_now.h>
#include <WiFi.h>
#include <esp_wifi.h>
#include "driver/can.h"
#include "rtc.h"
#include "rtc_clk_common.h"

#include "LoRaLib.h"

#include <data_types.h>
#include <pin_config.h>


/*
===============================================================================================
                                    Definitions
===============================================================================================
*/


// definitions
#define TIRE_DIAMETER                   20.0        // diameter of the vehicle's tires in inches
#define WHEEL_RPM_CALC_THRESHOLD        100         // the number of times the hall effect sensor is tripped before calculating vehicle speed
#define BRAKE_LIGHT_THRESHOLD           75          // the threshold that must be crossed for the brake to be considered active
#define PEDAL_MIN                       0           // minimum value the pedals can read as
#define PEDAL_MAX                       255         // maximum value a pedal can read as
#define PEDAL_DEADBAND                  15          // ~5% of PEDAL_MAX
#define MAX_TORQUE                      225         // MAX TORQUE RINEHART CAN ACCEPT, DO NOT EXCEED 230!!!
#define MIN_BUS_VOLTAGE                 150         // min bus voltage

// CAN
#define NUM_CAN_READS                   25          // the number of messages to read each time the CAN task is called
#define FCB_CONTROL_ADDR                0x00A       // critical data for FCB
#define FCB_DATA_ADDR                   0x00B       // sensor information for FCB
#define RCB_CONTROL_ADDR                0x00C       // critical data for RCB
#define RCB_DATA_ADDR                   0x00D       // sensor information for RCB 
#define RINE_CONTROL_ADDR               0x0C0       // motor command address 
#define RINE_MOTOR_INFO_ADDR            0x0A5       // get rinehart motor infromation 
#define RINE_VOLT_INFO_ADDR             0x0A7       // get rinehart voltage information

// ESP-NOW
#define WCB_ESP_NOW_ADDRESS             {0xC4, 0xDE, 0xE2, 0xC0, 0x75, 0x80}
#define FCB_ESP_NOW_ADDRESS             {0xC4, 0xDE, 0xE2, 0xC0, 0x75, 0x81}
#define RCB_ESP_NOW_ADDRESS             {0xC4, 0xDE, 0xE2, 0xC0, 0x75, 0x82}

// tasks & timers
#define SENSOR_POLL_INTERVAL            100000      // 0.1 seconds in microseconds
#define CAN_UPDATE_INTERVAL             100000      // 0.1 seconds in microseconds
#define ARDAN_UPDATE_INTERVAL           200000      // 0.2 seconds in microseconds
#define ESP_NOW_UPDATE_INTERVAL         200000      // 0.2 seconds in microseconds
#define TASK_STACK_SIZE                 4096        // in bytes
#define CAN_BLOCK_DELAY                 100         // time to block to complete function call in FreeRTOS ticks (milliseconds)

// debug
#define ENABLE_DEBUG                    false       // master debug message control
#if ENABLE_DEBUG
  #define MAIN_LOOP_DELAY               1000        // delay in main loop
#else
  #define MAIN_LOOP_DELAY               1
#endif


/*
===============================================================================================
                                  Global Variables
===============================================================================================
*/


/**
 * @brief debugger structure used for organizing debug information
 * 
 */
Debugger debugger = {
  // debug toggle
  .debugEnabled = ENABLE_DEBUG,
  .CAN_debugEnabled = false,
  .WCB_debugEnabled = false,
  .IO_debugEnabled = true,
  .scheduler_debugEnable = false,

  // debug data
  .CAN_rineCtrlResult = ESP_OK,
  .CAN_rcbCtrlResult = ESP_OK,
  .CAN_rineCtrlOutgoingMessage = {},
  .CAN_rcbCtrlOutgoingMessage = {},

  .RCB_updateResult = ESP_OK,
  .RCB_updateMessage = {},

  .WCB_updateResult = ESP_OK,
  .WCB_updateMessage = {},

  .IO_data = {},

  .ardanTransmitResult = 0,

  // scheduler data
  .sensorTaskCount = 0,
  .canTaskCount = 0,
  .ardanTaskCount = 0,
  .espnowTaskCount = 0,
};


/**
 * @brief the dataframe that describes the entire state of the car
 * 
 */
CarData carData = {
  // driving data
  .drivingData = {
    .readyToDrive = false,
    .enableInverter = false,
    .prechargeState = PRECHARGE_OFF,

    .imdFault = true,
    .bmsFault = true,

    .commandedTorque = 0,
    .currentSpeed = 0.0f,
    .driveDirection = false,
    .driveMode = ECO, 
  },

  // Battery Status
  .batteryStatus = {
    .batteryChargeState = 0,
    .busVoltage = 0,
    .rinehartVoltage = 0,
    .pack1Temp = 0.0f,
    .pack2Temp = 0.0f,
    .packCurrent = 0.0f,
    .minCellVoltage = 0.0f,
    .maxCellVoltage = 0.0f,
  },

  // Sensors
  .sensors = {
    .rpmCounterFR = 0,
    .rpmCounterFL = 0,
    .rpmCounterBR = 0,
    .rpmCounterBL = 0,
    .rpmTimeFR = 0,
    .rpmTimeFL = 0,
    .rpmTimeBR = 0,
    .rpmTimeBL = 0,

    .wheelSpeedFR = 0.0f,
    .wheelSpeedFL = 0.0f,
    .wheelSpeedBR = 0.0f,
    .wheelSpeedBL = 0.0f,

    .wheelHeightFR = 0.0f,
    .wheelHeightFL = 0.0f,
    .wheelHeightBR = 0.0f,
    .wheelHeightBL = 0.0f,

    .steeringWheelAngle = 0,

    .vicoreTemp = 0.0f,
    .pumpTempIn = 0.0f,
    .pumpTempOut = 0.0f,
  },

  // Inputs
  .inputs = {
    .pedal0 = 0,
    .pedal1 = 0,
    .brakeFront = 0,
    .brakeRear = 0,
    .brakeRegen = 0,
    .coastRegen = 0,
  },

  // Outputs
  .outputs = {
    .buzzerActive = false,
    .buzzerCounter = 0,
    .brakeLight = false,
    .fansActive = false,
    .pumpActive = false,
  }
};


// Hardware Timers
hw_timer_t *timer1 = NULL;
hw_timer_t *timer2 = NULL;
hw_timer_t *timer3 = NULL;
hw_timer_t *timer4 = NULL;
portMUX_TYPE timerMux = portMUX_INITIALIZER_UNLOCKED;


// ESP-NOW Peers
esp_now_peer_info_t wcbInfo = {
  .peer_addr = WCB_ESP_NOW_ADDRESS,
  .channel = 1,
  .ifidx = WIFI_IF_STA,
  .encrypt = false,
};

esp_now_peer_info_t rcbInfo = {
  .peer_addr = RCB_ESP_NOW_ADDRESS,
  .channel = 1,
  .ifidx = WIFI_IF_STA,
  .encrypt = false,
};


// CAN
static const can_general_config_t can_general_config = CAN_GENERAL_CONFIG_DEFAULT((gpio_num_t)CAN_TX_PIN, (gpio_num_t)CAN_RX_PIN, CAN_MODE_NORMAL);
static const can_timing_config_t can_timing_config = CAN_TIMING_CONFIG_500KBITS();
static const can_filter_config_t can_filter_config = CAN_FILTER_CONFIG_ACCEPT_ALL();


// LoRa Interface
// RFM95 lora = new LoRa();


/*
===============================================================================================
                                    Function Declarations 
===============================================================================================
*/


// callbacks
void SensorCallback();
void CANCallback();
void ARDANCallback();
void ESPNOWCallback();
void FRWheelSensorCallback();
void FLWheelSensorCallback();

// tasks
void ReadSensorsTask(void* pvParameters);
void UpdateCANTask(void* pvParameters);
void UpdateARDANTask(void* pvParameters);
void UpdateESPNOWTask(void* pvParameters);

// ISRs
void WCBDataReceived(const uint8_t* mac, const uint8_t* incomingData, int length);

// helpers
void GetCommandedTorque();
uint16_t CalculateThrottleResponse(uint16_t value);


/*
===============================================================================================
                                            Setup 
===============================================================================================
*/


void setup() {
  // set power configuration
  esp_pm_configure(&power_configuration);

  if (debugger.debugEnabled) {
    // delay startup by 3 seconds
    vTaskDelay(3000);
  }

  // -------------------------- initialize serial connection ------------------------ //
  Serial.begin(9600);
  Serial.printf("\n\n|--- STARTING SETUP ---|\n\n");

  // setup managment struct
  struct setup
  {
    bool ioActive = false;
    bool canActive = false;
    bool ardanActive = false;
    bool wcbActive = false;
    bool rcbActive = false;
  };
  setup setup;


  // -------------------------- initialize GPIO ------------------------------ //
  analogReadResolution(12);
  // analogSetAttenuation();
  
  // inputs
  pinMode(RTD_BUTTON_PIN, INPUT_PULLUP);

  pinMode(PEDAL_0_PIN, INPUT);
  pinMode(PEDAL_1_PIN, INPUT);

  pinMode(BRAKE_PIN, INPUT);
  
  pinMode(WHEEL_SPEED_FL_SENSOR, INPUT);
  pinMode(WHEEL_SPEED_FR_SENSOR, INPUT);

  pinMode(WHEEL_HEIGHT_FL_SENSOR, INPUT);
  pinMode(WHEEL_HEIGHT_FR_SENSOR, INPUT);

  pinMode(STEERING_WHEEL_POT, INPUT);

  // outputs
  pinMode(RTD_LED_PIN, OUTPUT);
  pinMode(WCB_CONNECTION_LED, OUTPUT);
  pinMode(BMS_LED_PIN, OUTPUT);
  pinMode(IMD_LED_PIN, OUTPUT);

  pinMode(BUZZER_PIN, OUTPUT);
  pinMode(CAN_ENABLE_PIN, OUTPUT);

  // interrupts
  attachInterrupt(WHEEL_HEIGHT_FR_SENSOR, FRWheelSensorCallback, ONHIGH);
  attachInterrupt(WHEEL_HEIGHT_FL_SENSOR, FLWheelSensorCallback, ONHIGH);

  Serial.printf("GPIO INIT [ SUCCESS ]\n");
  setup.ioActive = true;
  // -------------------------------------------------------------------------- //


  // --------------------- initialize CAN Controller -------------------------- //
  digitalWrite(CAN_ENABLE_PIN, LOW);

  // install CAN driver
  if(can_driver_install(&can_general_config, &can_timing_config, &can_filter_config) == ESP_OK) {
    Serial.printf("CAN DRIVER INSTALL [ SUCCESS ]\n");

    // start CAN bus
    if (can_start() == ESP_OK) {
      Serial.printf("CAN INIT [ SUCCESS ]\n");
      can_reconfigure_alerts(CAN_ALERT_ALL, NULL);

      setup.canActive = true;
    }

    else {
      Serial.printf("CAN INIT [ FAILED ]\n");
    }
  }

  else {
    Serial.printf("CAN DRIVER INSTALL [ FAILED ]\n");
  }


  // --------------------------------------------------------------------------- //


  // -------------------------- initialize ESP-NOW  ---------------------------- //
  // init wifi and config
  if (WiFi.mode(WIFI_STA)) {
    Serial.printf("WIFI INIT [ SUCCESS ]\n");

    // set custom mac address
    const uint8_t fcbAddress[6] = FCB_ESP_NOW_ADDRESS;
    if (esp_wifi_set_mac(WIFI_IF_STA, fcbAddress) == ESP_OK) {
      Serial.printf("WIFI SET MAC [ SUCCESS ]\n");
    
      esp_wifi_set_channel(1, WIFI_SECOND_CHAN_NONE);
      Serial.print("WIFI MAC: "); Serial.println(WiFi.macAddress());
      Serial.print("WIFI CHANNEL: "); Serial.println(WiFi.channel());

      if (esp_now_init() == ESP_OK) {
        Serial.printf("ESP-NOW INIT [ SUCCESS ]\n");

        // add peers
        esp_err_t rcbResult = esp_now_add_peer(&rcbInfo);
        esp_err_t wcbResult = esp_now_add_peer(&wcbInfo);

        if (rcbResult == ESP_OK && wcbResult == ESP_OK) {
          Serial.printf("ESP-NOW ADD PEERS [ SUCCESS ]\n");

          setup.rcbActive = true;
          setup.wcbActive = true;
        }
        else {
          Serial.printf("ESP-NOW ADD PEERS [ FAILED ]\n");
        }
      }

      else {
        Serial.printf("ESP-NOW INIT [ FAILED ]\n");
      }
    }
    else {
      Serial.printf("WIFI SET MAC [ FAILED ]\n");
    }
  }

  else {
    Serial.printf("WIFI INIT [ FAILED ]\n");
  }

  // ------------------------------------------------------------------------ //


  // ------------------- initialize ARDAN Connection ------------------------ //
  // LoRa Interface

  // // init lora
  // if (lora.begin() == ERR_NONE) {
  //   Serial.printf("ARDAN INIT [SUCCESSS ]\n");

  //   // set the sync word so the car and monitoring station can communicate
  //   lora.setSyncWord(0xA1);         // the channel to be transmitting on (range: 0x00 - 0xFF)

  // setup.ardanActive = true;
  // }
  // else { 
  //   Serial.printf("ARDAN INIT [ FAILED ]\n");
  // }send message
  // ------------------------------------------------------------------------- //


  // ---------------------- initialize timer interrupts --------------------- //
  // timer 1 - Read Sensors 
  timer1 = timerBegin(0, 80, true);
  timerAttachInterrupt(timer1, &SensorCallback, true);
  timerAlarmWrite(timer1, SENSOR_POLL_INTERVAL, true);

  // timer 2 - CAN Update
  timer2 = timerBegin(1, 80, true);
  timerAttachInterrupt(timer2, &CANCallback, true);
  timerAlarmWrite(timer2, CAN_UPDATE_INTERVAL, true);

  // timer 3 - ARDAN Update
  timer3 = timerBegin(2, 80, true);
  timerAttachInterrupt(timer3, &ARDANCallback, true);
  timerAlarmWrite(timer3, ARDAN_UPDATE_INTERVAL, true);

  // timer 4 - ESP-NOW Update
  timer4 = timerBegin(3, 80, true);
  timerAttachInterrupt(timer4, &ESPNOWCallback, true);
  timerAlarmWrite(timer4, ESP_NOW_UPDATE_INTERVAL, true);

  // start timers
  if (setup.ioActive)
    timerAlarmEnable(timer1);
  if (setup.canActive)
    timerAlarmEnable(timer2);
  if (setup.ardanActive)
    timerAlarmEnable(timer3);
  if (setup.wcbActive && setup.rcbActive)
    timerAlarmEnable(timer4);
  // ----------------------------------------------------------------------------------------- //


  // ------------------------------- Scheduler & Task Status --------------------------------- //
  Serial.printf("SENSOR TASK STATUS: %s\n", timerAlarmEnabled(timer1) ? "RUNNING" : "DISABLED");
  Serial.printf("CAN TASK STATUS: %s\n", timerAlarmEnabled(timer2) ? "RUNNING" : "DISABLED");
  Serial.printf("ARDAN TASK STATUS: %s\n", timerAlarmEnabled(timer3) ? "RUNNING" : "DISABLED");
  Serial.printf("ESP-NOW TASK STATUS: %s\n", timerAlarmEnabled(timer4) ? "RUNNING" : "DISABLED");
  
  // scheduler status
  if (xTaskGetSchedulerState() == 2) {
    Serial.printf("\nScheduler Status: RUNNING\n");

    // clock frequency
    rtc_cpu_freq_config_t clock_config;
    rtc_clk_cpu_freq_get_config(&clock_config);
    Serial.printf("CPU Frequency: %dMHz\n", clock_config.freq_mhz);
  }
  else {
    Serial.printf("\nScheduler STATUS: FAILED\nHALTING OPERATIONS");
    while (1) {};
  }
  Serial.printf("\n\n|--- END SETUP ---|\n\n");
  // ---------------------------------------------------------------------------------------- //
}
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
void loop()
{
  // everything is managed by RTOS, so nothing really happens here!
  vTaskDelay(MAIN_LOOP_DELAY);    // prevent watchdog from getting upset

  // debugging
  if (debugger.debugEnabled) {
    PrintDebug();
  }
}


/**
 * @brief Get the Commanded Torque from pedal values
 */
void GetCommandedTorque()
{
  // get the pedal average
  int pedalAverage = (carData.inputs.pedal0 + carData.inputs.pedal1) / 2;

  // drive mode logic (values are 10x because that is the format for Rinehart)
  switch (carData.drivingData.driveMode)
  {
    case SLOW:  // runs at 50% power
      carData.drivingData.commandedTorque = map(pedalAverage, PEDAL_MIN, PEDAL_MAX, 0, (MAX_TORQUE * 10) * 0.50);
    break;

    case ECO:   // runs at 75% power
      carData.drivingData.commandedTorque = map(pedalAverage, PEDAL_MIN, PEDAL_MAX, 0, (MAX_TORQUE * 10) * 0.75);
    break;

    case FAST:  // runs at 100% power
      carData.drivingData.commandedTorque = map(pedalAverage, PEDAL_MIN, PEDAL_MAX, 0, (MAX_TORQUE * 10));
    break;
    
    // error state, set the mode to ECO
    default:
      // set the state to ECO for next time
      carData.drivingData.driveMode = ECO;

      // we don't want to send a torque command if we were in an undefined state
      carData.drivingData.commandedTorque = 0;
    break;
  }

  // --- safety checks --- //

  // rinehart voltage check
  if (carData.batteryStatus.rinehartVoltage < MIN_BUS_VOLTAGE) {
    carData.drivingData.enableInverter = false;
  }

  // pedal difference 
  int pedalDifference = carData.inputs.pedal0 - carData.inputs.pedal1;
  if (_abs(pedalDifference > (PEDAL_MAX * 0.15))) {
    carData.drivingData.commandedTorque = 0;
  }
  
  // buffer overflow / too much torque somehow
  if ((carData.drivingData.commandedTorque > (MAX_TORQUE * 10)) || (carData.drivingData.commandedTorque < 0)) {
    carData.drivingData.commandedTorque = 0;
  }

  // if brake is engaged
  if (carData.outputs.brakeLight) {
    carData.drivingData.commandedTorque = 0;
  }

  // check if ready to drive
  if (!carData.drivingData.readyToDrive) {
    carData.drivingData.commandedTorque = 0;      // if not ready to drive then block all torque
  }
} 


/**
 * @brief calculate throttle response of pedal
 * 
 * @param value the raw pedal value
 * @return uint16_t the commanded torque value
 */
uint16_t CalculateThrottleResponse(uint16_t value) 
{
  // inits
  float calculatedResponse = 0;
  float exponent = 0;

  // check for buffer overflow
  if (value > 255 || value < 0) {
    return 0;
  }

  // account for deadband
  if (value < PEDAL_DEADBAND) {
    return 0;
  }

  // determine response curve based on drive mode
  switch (carData.drivingData.driveMode)
  {
    case SLOW:
      exponent = 4.0;
      calculatedResponse = (pow(value, exponent)) / (pow(PEDAL_MAX, exponent) / MAX_TORQUE);
    break;

    case ECO:
      exponent = 2.0;
      calculatedResponse = (pow(value, exponent)) / (pow(PEDAL_MAX, exponent) / MAX_TORQUE);
    break;

    case FAST:
      exponent = 0.75;
      calculatedResponse = (pow(value, exponent)) / (pow(PEDAL_MAX, exponent) / MAX_TORQUE);
    break;
    
    // if we are in an undefined state, pedals should do nothing
    default:
      return 0;
    break;
  }

  // cast final calculated response to an int
  return (int)calculatedResponse;
}


/* 
===============================================================================================
                                    DEBUG FUNCTIONS
================================================================================================
*/


/**
 * @brief some nice in-depth debugging for CAN
 * 
 */
void PrintCANDebug() {
  Serial.printf("\n--- START CAN DEBUG ---\n\n");
  // bus alerts            
  Serial.printf("CAN BUS Alerts:\n");
  uint32_t alerts;
  can_read_alerts(&alerts, pdMS_TO_TICKS(100));
  if (alerts & CAN_ALERT_TX_SUCCESS) {
    Serial.printf("CAN ALERT: TX Success\n");
  }
  if (alerts & CAN_ALERT_TX_FAILED) {
    Serial.printf("CAN ALERT: TX Failed\n");
  }
  if (alerts & CAN_ALERT_RX_QUEUE_FULL) {
    Serial.printf("CAN ALERT: RX Queue Full\n");
  }
  if (alerts & CAN_ALERT_ABOVE_ERR_WARN) {
    Serial.printf("CAN ALERT: Surpassed Error Warning Limit\n");
  }
  if (alerts & CAN_ALERT_ERR_PASS) {
    Serial.printf("CAN ALERT: Entered Error Passive state\n");
  }
  if (alerts & CAN_ALERT_BUS_OFF) {
    Serial.printf("CAN ALERT: Bus Off\n");
  }

  Serial.printf("\n");

  // incoming data
  Serial.printf("Incoming RTD Status: %s\n", carData.drivingData.readyToDrive ? "true" : "false");
  Serial.printf("Incoming IMD Fault Status: %s\n", carData.drivingData.imdFault ? "cleared" : "fault state");
  Serial.printf("Incoming BMS Fault Status: %s\n", carData.drivingData.bmsFault ? "fault state" : "cleared");

  // sent status
  Serial.printf("Rine Ctrl Send Status: 0x%X\n", debugger.CAN_rineCtrlResult);
  Serial.printf("RCB Ctrl Send Status: 0x%X\n", debugger.CAN_rcbCtrlResult);

  // messages
  Serial.printf("\n");
  Serial.printf("Rine Ctrl Outgoing Message:\n");
  for (int i = 0; i < 8; ++i) {
    Serial.printf("Byte %d: %02X\t", i, debugger.CAN_rineCtrlOutgoingMessage[i]);
  }

  Serial.printf("\n");

  Serial.printf("RCB Ctrl Outgoing Message:\n");
  for (int i = 0; i < 8; ++i) {
    Serial.printf("Byte %d: %02X\t", i, debugger.CAN_rcbCtrlOutgoingMessage[i]);
  }

  Serial.printf("\n\n--- END CAN DEBUG ---\n");
}


/**
 * @brief some nice in-depth debugging for WCB updates
 * 
 */
void PrintWCBDebug() {
  Serial.printf("\n--- START WCB DEBUG ---\n");

  // send status
  Serial.printf("WCB ESP-NOW Update: %s\n", debugger.WCB_updateResult ? "Success" : "Failed");


  Serial.printf("\n--- END WCB DEBUG ---\n");
}


/**
 * @brief some nice in-depth debugging for I/O
 * 
 */
void PrintIODebug() {
  Serial.printf("\n--- START I/O DEBUG ---\n");

  // INPUTS
  // pedal 0 & 1
  Serial.printf("Pedal 0: %d\tPedal 1: %d\n", debugger.IO_data.inputs.pedal0, debugger.IO_data.inputs.pedal1);	

  // brake 0 & 1
  Serial.printf("Brake Front: %d\tBrake Rear: %d\n", debugger.IO_data.inputs.brakeFront, debugger.IO_data.inputs.brakeRear);

  // brake regen
  Serial.printf("Brake Regen: %d\n", debugger.IO_data.inputs.brakeRegen);

  // coast regen
  Serial.printf("Coast Regen: %d\n", debugger.IO_data.inputs.coastRegen);

  // faults
  Serial.printf("Faults: IMD: %d | BMS: %d\n", carData.drivingData.imdFault, carData.drivingData.bmsFault);

  // rtd
  Serial.printf("Ready to Drive: %s\n", carData.drivingData.readyToDrive ? "READY" : "DEACTIVATED");

  // inverter
  Serial.printf("Inverter Enable: %s\n", carData.drivingData.enableInverter ? "ENABLED" : "DISABLED");

  // OUTPUTS
  Serial.printf("Buzzer Status: %s, Buzzer Counter: %d\n", debugger.IO_data.outputs.buzzerActive ? "On" : "Off", debugger.IO_data.outputs.buzzerCounter);

  Serial.printf("Commanded Torque: %d\n", carData.drivingData.commandedTorque);
  
  Serial.printf("Drive Mode: %d\n", (int)carData.drivingData.driveMode);

  Serial.printf("\n--- END I/O DEBUG ---\n");
}


/**
 * @brief manages toggle-able debug settings
 * 
 */
void PrintDebug() {
  // CAN
  if (debugger.CAN_debugEnabled) {
      PrintCANDebug();
  }

  // WCB
  if (debugger.WCB_debugEnabled) {
    PrintWCBDebug();
  }

  // I/O
  if (debugger.IO_debugEnabled) {
    PrintIODebug();
  }

  // Scheduler
  if (debugger.scheduler_debugEnable) {
    Serial.printf("sensor: %d | can: %d | wcb: %d | rcb: %d | ardan: %d\n", debugger.sensorTaskCount, debugger.canTaskCount,
    debugger.espnowTaskCount, debugger.espnowTaskCount, 
    debugger.ardanTaskCount);
  }
}

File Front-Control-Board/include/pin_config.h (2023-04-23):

/**
 * @file pinConfig.h
 * @author dominic gasperini 
 * @brief this file holds the pin layout for the board I/O
 * @version 1.0
 * @date 2023-03-22
 * 
 * @copyright Copyright (c) 2022
 * 
 */


// includes
#include <esp_pm.h>

/*
===========================================================
                    Power Configuration
===========================================================
*/

esp_pm_config_esp32_t power_configuration {
    .max_freq_mhz = 240,   
    .min_freq_mhz = 240,
    .light_sleep_enable = false,
};


/*
===========================================================
                    Pin Definitions
===========================================================
*/


// Sensors
#define WHEEL_SPEED_FR_SENSOR               36
#define WHEEL_SPEED_FL_SENSOR               39

#define WHEEL_HEIGHT_FR_SENSOR              34
#define WHEEL_HEIGHT_FL_SENSOR              35

#define STEERING_WHEEL_POT                  32

#define PEDAL_0_PIN                         33
#define PEDAL_1_PIN                         25
#define BRAKE_PIN                           4

// Inputs
#define RTD_BUTTON_PIN                      17

// CAN
#define CAN_RX_PIN                          19
#define CAN_TX_PIN                          23
#define CAN_ENABLE_PIN                      5

// Outputs
#define RTD_LED_PIN                         21
#define WCB_CONNECTION_LED                  26

#define BMS_LED_PIN                         1
#define IMD_LED_PIN                         3

#define BUZZER_PIN                          16

#define ARDAN_MISO_PIN                      12
#define ARDAN_MOSI_PIN                      13
#define ARDAN_CS_PIN                        10

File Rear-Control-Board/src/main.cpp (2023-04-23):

/**
 * @file main.cpp
 * @author Dominic Gasperini - UVM '23
 * @brief this drives the rear control board on clean speed 5.5
 * @version 1.0
 * @date 2023-04-03
 */


/*
===============================================================================================
                                    Includes 
===============================================================================================
*/
// standard includes 
#include <Arduino.h>
#include <esp_now.h>
#include <WiFi.h>
#include <esp_wifi.h>
#include "driver/can.h"
#include "rtc.h"
#include "rtc_clk_common.h"
#include "driver/can.h"

#include "FS.h"
#include "SD_MMC.h"

#include <pin_config.h>
#include <data_types.h>


/*
===============================================================================================
                                    Definitions
===============================================================================================
*/


// SD Card
#define SD_BUFF_LEN                     128

// definitions
#define TIRE_DIAMETER                   20.0        // diameter of the vehicle's tires in inches
#define WHEEL_RPM_CALC_THRESHOLD        25          // the number of times the hall effect sensor is tripped before calculating vehicle speed
#define PRECHARGE_FLOOR                 0.8         // minimum percentage of acceptable voltage to run car
#define MIN_BUS_VOLTAGE                 150         // this should be a voltage that can only be met if 1 pack is connected

// CAN
#define NUM_CAN_READS                   25          // in general, the number of expected messages times 2, so 6 
#define FCB_CONTROL_ADDR                0x00A       // 
#define FCB_DATA_ADDR                   0x00B       // 
#define RCB_CONTROL_ADDR                0x00C       // address for critical data sharing
#define RCB_DATA_ADDR                   0x00D       // address for non-critical data sharing
#define RINE_MOTOR_INFO_ADDR            0x0A5       // get motor information from Rinehart 
#define RINE_VOLT_INFO_ADDR             0x0A7       // get rinehart electrical information
#define RINE_BUS_INFO_ADDR              0x0AA       // get rinehart relay information 
#define RINE_BUS_CONTROL_ADDR           0x0C1       // control rinehart relay states
#define BMS_GEN_DATA_ADDR               0x6B0       // important BMS data
#define BMS_CELL_DATA_ADDR              0x6B2       // cell data

// ESP-NOW
#define WCB_ESP_NOW_ADDRESS             {0xC4, 0xDE, 0xE2, 0xC0, 0x75, 0x80}
#define FCB_ESP_NOW_ADDRESS             {0xC4, 0xDE, 0xE2, 0xC0, 0x75, 0x81}
#define RCB_ESP_NOW_ADDRESS             {0xC4, 0xDE, 0xE2, 0xC0, 0x75, 0x82}

// tasks & timers
#define SENSOR_POLL_INTERVAL            100000      // 0.1 seconds in microseconds
#define ESP_NOW_UPDATE_INTERVAL         200000      // 0.2 seconds in microseconds
#define CAN_UPDATE_INTERVAL             100000      // 0.1 seconds in microseconds
#define LOGGER_UPDATE_INTERVAL          200000      // 0.2 seconds in microseconds
#define TASK_STACK_SIZE                 4096        // in bytes
#define CAN_BLOCK_DELAY                 100         // time to block to complete function call in FreeRTOS ticks (milliseconds)

// debug
#define ENABLE_DEBUG                    true       // master debug control
#if ENABLE_DEBUG
  #define MAIN_LOOP_DELAY               1000
#else
  #define MAIN_LOOP_DELAY               1
#endif


/*
===============================================================================================
                                  Global Variables
===============================================================================================
*/


/**
 * @brief debugger structure used for organizing debug information
 * 
 */
Debugger debugger = {
  // debug toggle
  .debugEnabled = ENABLE_DEBUG,
  .CAN_debugEnabled = false,
  .IO_debugEnabled = true,
  .Logger_debugEnabled = false,
  .scheduler_debugEnable = false,

  // debug data
  .prechargeResult = ESP_OK,
  .fcbCtrlResult = ESP_OK,
  .fcbDataResult = ESP_OK,
  
  .CAN_prechargeOutgoingMessage = {},
  .CAN_fcbDataOutgoingMessage = {},
  .CAN_fcbCtrlOutgoingMessage = {},

  .WCB_updateResult = ESP_OK,
  .WCB_updateMessage = {},

  .IO_data = {},

  .prechargeState = PRECHARGE_OFF,

  // scheduler data
  .sensorTaskCount = 0,
  .prechargeTaskCount = 0,
  .canReadTaskCount = 0,
  .canWriteTaskCount = 0,
  .loggerTaskCount = 0,
  .wcbTaskCount = 0,
};


/**
 * @brief the dataframe that describes the entire state of the car
 * 
 */
CarData carData = {
  // driving data
  .drivingData = {
    .readyToDrive = false,
    .enableInverter = false,
    .prechargeState = PRECHARGE_OFF,

    .imdFault = true,
    .bmsFault = true,

    .commandedTorque = 0,
    .currentSpeed = 0.0f,
    .driveDirection = true,
    .driveMode = ECO, 
  },

  // Battery Status
  .batteryStatus = {
    .batteryChargeState = 0,
    .busVoltage = 0,
    .rinehartVoltage = 0,
    .pack1Temp = 0.0f,
    .pack2Temp = 0.0f,
    .packCurrent = 0.0f,
    .minCellVoltage = 0.0f,
    .maxCellVoltage = 0.0f,
  },

  // Sensors
  .sensors = {
    .rpmCounterFR = 0,
    .rpmCounterFL = 0,
    .rpmCounterBR = 0,
    .rpmCounterBL = 0,
    .rpmTimeFR = 0,
    .rpmTimeFL = 0,
    .rpmTimeBR = 0,
    .rpmTimeBL = 0,

    .wheelSpeedFR = 0.0f,
    .wheelSpeedFL = 0.0f,
    .wheelSpeedBR = 0.0f,
    .wheelSpeedBL = 0.0f,

    .wheelHeightFR = 0.0f,
    .wheelHeightFL = 0.0f,
    .wheelHeightBR = 0.0f,
    .wheelHeightBL = 0.0f,

    .steeringWheelAngle = 0,

    .vicoreTemp = 0.0f,
    .pumpTempIn = 0.0f,
    .pumpTempOut = 0.0f,
  },

  // Inputs
  .inputs = {
    .pedal0 = 0,
    .pedal1 = 0,
    .brakeFront = 0,
    .brakeRear = 0,
    .brakeRegen = 0,
    .coastRegen = 0,
  },

  // Outputs
  .outputs = {
    .buzzerActive = false,
    .buzzerCounter = 0,
    .brakeLight = false,
    .fansActive = false,
  }
};


// Hardware Timers
hw_timer_t *timer1 = NULL;
hw_timer_t *timer2 = NULL;
hw_timer_t *timer3 = NULL;
hw_timer_t *timer4 = NULL;
portMUX_TYPE timerMux = portMUX_INITIALIZER_UNLOCKED;


// ESP-NOW Peers
esp_now_peer_info_t wcbInfo = {
  .peer_addr = WCB_ESP_NOW_ADDRESS,
  .channel = 1,
  .ifidx = WIFI_IF_STA,
  .encrypt = false,
};

esp_now_peer_info_t fcbInfo = {
  .peer_addr = FCB_ESP_NOW_ADDRESS,
  .channel = 1,
  .ifidx = WIFI_IF_STA,
  .encrypt = false,
};


// CAN
static const can_timing_config_t can_timing_config = CAN_TIMING_CONFIG_500KBITS();
static const can_filter_config_t can_filter_config = CAN_FILTER_CONFIG_ACCEPT_ALL();
// {
//   .acceptance_code = 0x000, // begin range
//   .acceptance_mask = 0x0C4, // end range
//   .single_filter = true
// };
static const can_general_config_t can_general_config = CAN_GENERAL_CONFIG_DEFAULT((gpio_num_t)CAN_TX_PIN, (gpio_num_t)CAN_RX_PIN, CAN_MODE_NORMAL);


// SD Card Interface
int sdLogFileNumber;
char sdTrackerFilename[SD_BUFF_LEN] = "/tracker.txt";
char sdLogFilname [SD_BUFF_LEN] = "";
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

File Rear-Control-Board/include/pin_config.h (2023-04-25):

/**
 * @file pin_config.h
 * @author Dominic Gasperini 
 * @brief this file holds the pin layout for the board I/O
 * @version 1.0
 * @date 2023-02-21
 * 
 * @copyright Copyright (c) 2022
 * 
 */


// includes
#include <esp_pm.h>


/*
===========================================================
                    Power Configuration
===========================================================
*/

esp_pm_config_esp32_t power_configuration {
    .max_freq_mhz = 240,   
    .min_freq_mhz = 240,
    .light_sleep_enable = false,
};


/*
===========================================================
                    Pin Definitions
===========================================================
*/


// Sensors
#define WHEEL_SPEED_BR_SENSOR               36
#define WHEEL_SPEED_BL_SENSOR               39

#define WHEEL_HEIGHT_BR_SENSOR              34
#define WHEEL_HEIGHT_BL_SENSOR              33


// Inputs
#define RAD_TEMP_IN_PIN                     4
#define RAD_TEMP_OUT_PIN                    0

#define IMD_FAULT_PIN                       32
#define BMS_FAULT_PIN                       35

// CAN
#define CAN_RX_PIN                          23
#define CAN_TX_PIN                          19


// Outputs
#define FAN_ENABLE_PIN                      26
#define PUMP_ENABLE_PIN                     2
#define BRAKE_LIGHT_PIN                     25
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

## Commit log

2022-07-28 decreased sensor poll interval
2022-08-04 switched to esp32-wroom-32e real quick
2022-08-04 did some lcd and button interrupts stuff
2022-08-10 fixed some mistakes and added some LCD stuff
    [main.cpp]
2022-08-10 added LED code
2022-08-10 updated timer timings
2022-08-10 fixed bugs and added comments
    [main.cpp]
2022-08-27 added rear control board folder
2022-08-31 fixed adc channel 2 and wifi module conflict
    [main.cpp]
2022-08-31 timer for buzzer is now dynamically managed
    [main.cpp]
2022-09-12 Tutorials and front board
    [Front Board.kicad_pcb, Front Board.kicad_sch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]
2022-09-20 front board update
    [AERO ATTENDANCE.xlsx, Front Board.kicad_sch, USB-interface.kicad_sch]
2022-10-03 Front board finished schematic
    [Front Board.kicad_sch, USB-interface.kicad_sch]
2022-10-03 Front board schematic
    and linking to footprint done
    [Front Board.kicad_pcb, Front Board.kicad_sch]
2022-10-03 front board with footprint
    [Front Board.kicad_pcb, Front Board.kicad_sch]
2022-10-04 Initial board creation
    [BoardV1Proto.kicad_pcb, BoardV1Proto.kicad_sch]
2022-10-10 Colin Push
    [Front Board.kicad_pcb, Front Board.kicad_sch, kicad_Basics.kicad_pcb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]
2022-10-11 Front board first draft
    [Front Board.kicad_pcb, Front Board.kicad_sch]
2022-10-17 fixed up car data struct
    [main.cpp]
2022-10-18 Added lin reg and more
    [BoardV1Proto.kicad_pcb, BoardV1Proto.kicad_sch]
2022-10-21 created rear control board project!
2022-10-21 updated folder names
    [Tractive_system.kicad_pcb, Tractive_system.kicad_sch]
2022-10-21 Started rework
    Started reworking the board to fit new board type, added a shortcuts sheet txt so I can remember, and did some general clean up.
    [BoardV1Proto.kicad_sch]
2022-11-02 updated pins schematic
    [Front Board.kicad_sch]
2022-11-02 pin layout updated needs PCB
    [Front Board.kicad_pcb, Front Board.kicad_sch]
2022-11-03 Front board updated just needs traces
    [Front Board.kicad_pcb, Front Board.kicad_sch]
2022-11-05 Front Board V1
    [Front Board.kicad_pcb, Front Board.kicad_sch]
2022-11-08 Added HVB V1, and re-push of second PACman
    [TSAL.kicad_sch, TSAL.sch, controller.kicad_sch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]
2022-11-08 Repush of initial Pacman
    [pacman-B_Cu.gbr, pacman-B_Mask.gbr, pacman-B_Paste.gbr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]
2022-11-08 fixed edge cuts
    [high-voltage-board.kicad_pcb, pacman halfway.kicad_pcb, pacman_side_2.kicad_pcb]
2022-11-11 Re adding work from 11/11/2022
    Un messing up by adding another version from before a push
    [BoardV1Proto.kicad_pcb, BoardV1Proto.kicad_sch]
2022-11-22 pcb Done? check SD
    [Controller.kicad_sch, FAULT_LATCHER.kicad_sch, FET_OUTPUT.kicad_sch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]
2022-11-28 Pacman 1 Correction+Reload
    [pacman halfway.kicad_pcb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]
2022-11-28 Pac2 Cleanup
    [pacman_side_2-B_Cu.gbr, pacman_side_2-B_Mask.gbr, pacman_side_2-B_Paste.gbr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]
2022-11-29 V1 with all Gerbers
    [Front Board-B_Cu.gbr, Front Board-B_Mask.gbr, Front Board-B_Paste.gbr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]
2022-11-29 cleaned up
    [BoardV1Proto.kicad_pcb, BoardV1Proto.kicad_sch, TSAL.kicad_sch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]
2023-01-25 updated interrupts to have ISR switches
2023-01-25 added debugging tracking to interrupts
2023-01-25 implemented CAN debugging print
2023-01-25 added print for some clarity
2023-01-25 implemented WCB debug prints
2023-01-27 overhauled timers so now they don't suck
2023-01-27 updated setup prints to use esp logging
2023-01-27 switched gpio & wifi from arduino to esp32 api
2023-01-30 cranked power
2023-01-30 updated poll sensors task
2023-02-01 started implementing custom display driver library
2023-02-01 wcb debugger feautre and hall effect callback
2023-02-01 implemented gpio for fr & fl hall effects
2023-02-01 more work on gpio & adc config
2023-02-06 typo and potential bug fix
    [main.cpp]
2023-02-06 applied potential bug fix
    [main.cpp]
2023-02-06 gone and done some more bug squashin
    [main.cpp]
2023-02-06 zip zop there go mistakes
    [main.cpp]
2023-02-08 updated setup prints
2023-02-08 fixed debug counter typo
    [main.cpp]
2023-02-17 updated wcb led conn pin
2023-02-21 added brake light code
2023-02-21 updated car data typo & added pump temp reads
2023-02-24 updated debugger, added wcb update, & filtered incoming fcb data
2023-02-25 fixed gpio mostly probably
    [main.cpp]
2023-02-25 added can stuff and fixed some bugs
    [main.cpp]
2023-02-26 updated filenames and setup some adc stuff
2023-02-27 fixed dependencies & added some GUI elements
    [main.cpp]
2023-02-28 added screen reset things
    [main.cpp]
2023-02-28 setup button interrupts
2023-02-28 fixed some bugs and now it works
    [main.cpp]
2023-03-01 fixed bug and cranked
    [main.cpp, pin_config.h]
2023-03-06 removed board design stuff
    [Accumulator_Container.kicad_sch, Controller.kicad_sch, Controller.sch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]
2023-03-06 last board file
2023-03-06 found more hidden board files
2023-03-27 got pedal calibrated and working
2023-03-28 fixed can stdby mode issue
    [main.cpp, pin_config.h]
2023-03-31 boy oh boy arduino moments are flying
2023-04-02 switched back to esp32 CAN library
2023-04-03 fixed weird gpio bug
    [main.cpp, pin_config.h]
2023-04-04 fixed bit shifting and improved can debugging
    [main.cpp]
2023-04-04 calibrated pedals
2023-04-05 fixed tasks and now then all run nice
    [main.cpp]
2023-04-05 fixed up sd card code
    [main.cpp]
2023-04-05 fixed task timing bug & general clean up
    [main.cpp, pin_config.h]
2023-04-05 fixed can timer interval
    [main.cpp]
2023-04-06 front board pins correct
    [pin_config.h]
2023-04-10 updated BMS CAN address stuff
2023-04-15 updated brake code
2023-04-16 added fault led switching
2023-04-17 updated LEDs
2023-04-18 fixed the inverted thing
    [main.cpp]
2023-04-19 optimized sensor reads and updated names
2023-04-20 gave leds back
2023-04-23 updated bms fault
2023-04-23 fixed comments and bms fault polarity
    [main.cpp]
2023-04-25 added custom throttle response for each drive mode
2023-04-26 replaced magic with def
    [main.cpp]
2023-04-27 increased brake threshold
